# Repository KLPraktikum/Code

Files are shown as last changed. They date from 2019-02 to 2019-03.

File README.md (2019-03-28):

# Code
Sämtlicher Code (Datenbank, Klasse, Main) für das Projekt

##Kommunikationsprotokoll:
	1= gelbe Tonne
	2= schwarze Tonne
	3= grüne Tonne
	4= braune Tonne
	
	s= successful
	t= timeout

##Ablauf:
	Raspberry (1-4) -> Arduino
	Arduino steuert LEDs an
	Arduino überprüft zu benutzenden Sensor
	Arduino (s/t) -> Raspberry
	Raspberry verarbeitet Daten, je nachdem ob s oder t (Punktesystem)

##Stromverbrauch@5V
- Arduino Nano 16Mhz @ 5V - 10mA (Datenblatt)
- Propeller Board @ 5V - 300mA (Datenblatt worst case)
- VL53L0X TOF Sensor @ 3.3V - 20mA (Active)/10uA ~= 0 (Datenblatt)
- APA102 LEDs @ 5V - ~1A pro Meter bei voller Helligkeit

| Komponente 	| Leistungsaufnahme (W)  	| Duty-Cycle  	| Anzahl	|
|:-:	|:-:	|:-:	|:-:	|
| Arduino Nano  	| 0,05W  	| 100%  	|1	|
| Propeller Board  	| 1,5W  	| 100%  	|1	|
| VL53L0X  	| ((3,3×0,02×20+3,3×0,00001)÷20)×4=0,069697742W  	| 5%  	|4	|
| APA102  	| ((5W÷3)×0,05)=0,083333333W  	| 5%  	|1	|

Insgesamt: 1,6W im Durchschnitt

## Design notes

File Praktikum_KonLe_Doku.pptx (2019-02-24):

## SmartBin Public.Efficient.Easy.

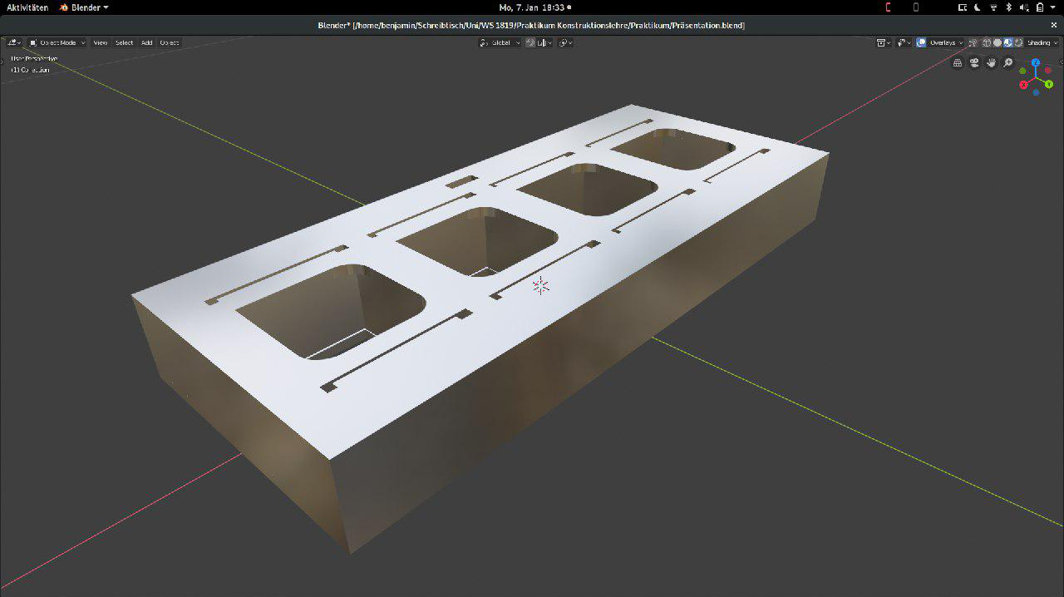
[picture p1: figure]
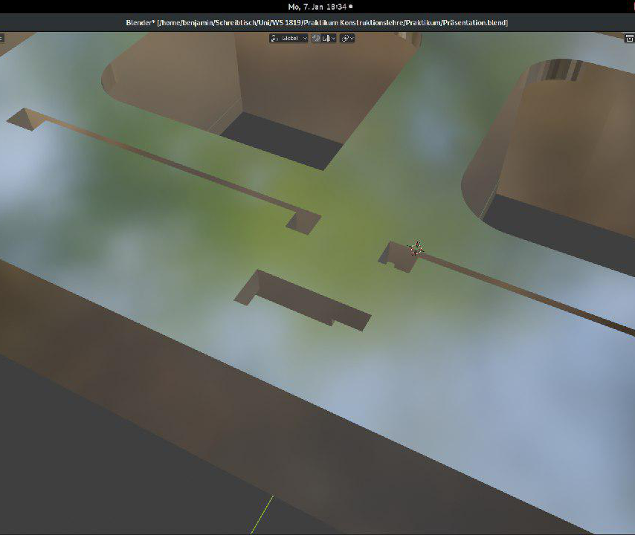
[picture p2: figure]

Präsentation für
das Praktikum Konstruktionslehre
Leitung:
Prof. Dr. Lars Mikelsons
Studenten:
Cindy Ebertz, Benjamin Ritter,
Marcel Khodabakhsh

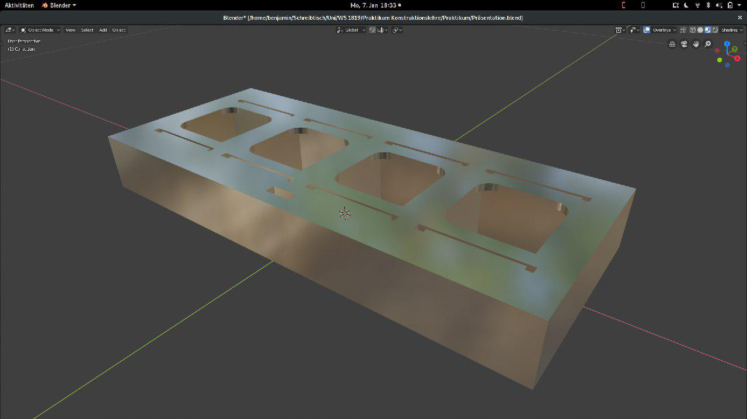
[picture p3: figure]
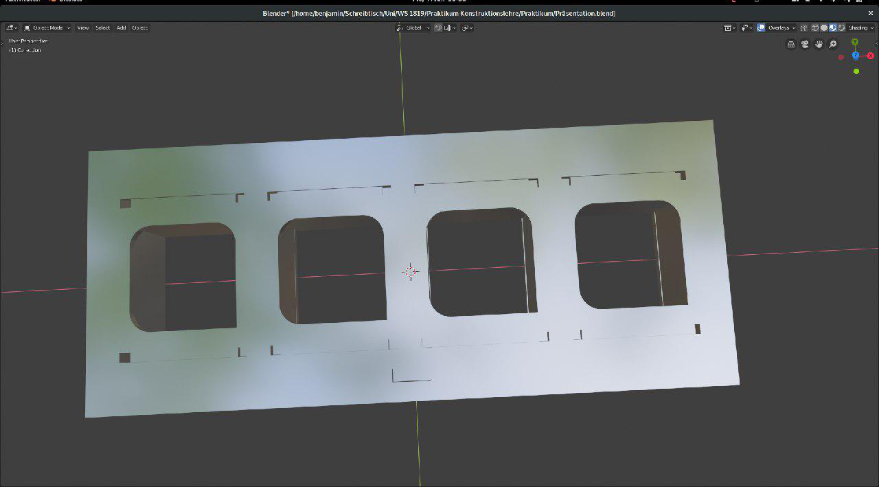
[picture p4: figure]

## Gliederung

1. Motivation für das Projekt
2. Vorführung mit Prototyp
3. Dokumentation
  a. Anforderungsermittlung
  b. Systementwurf & -architektur
  c. Systemintegration & - test
  d. Systemvalidierung

## Motivation für das Projekt

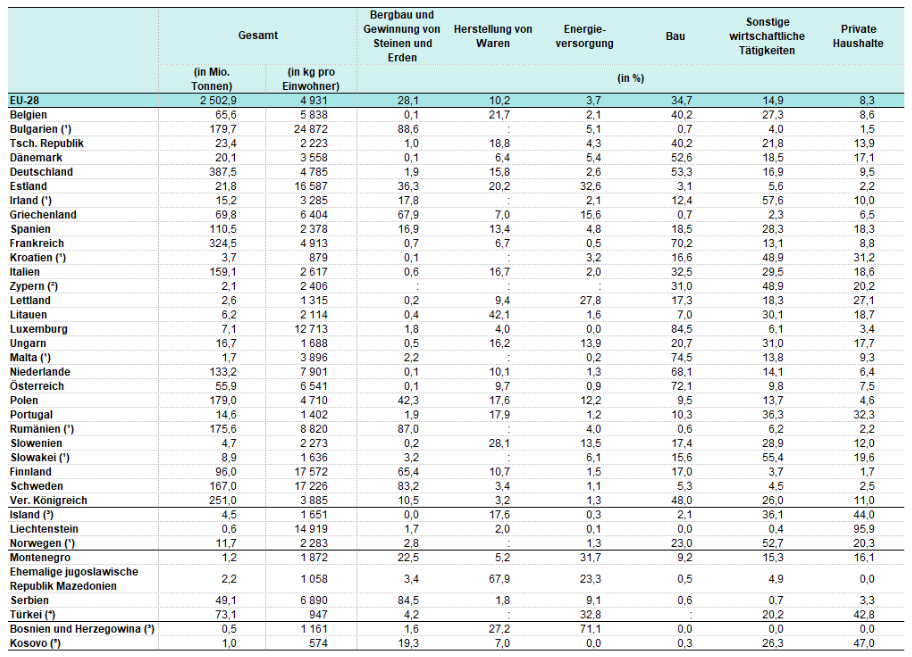
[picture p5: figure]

Praktikum Konstruktionslehre WiSe 2018/19

24.02.2019

3

- Deutschland produziert mehr Müll als jedes andere europäische Land
- Verbesserung des Recyclings für den Umweltschutz
- Unsere Mülltonne soll das vor allem an öffentlichen Plätzen / Bahnhöfen u.Ä. ermöglichen
Abbildung 1:
Abfallaufkommen in Europa
Quelle: Eurostat 2017

## Motivation für das Projekt

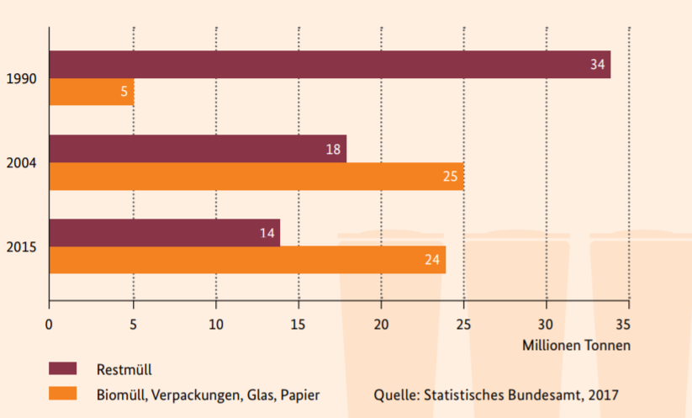
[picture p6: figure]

Praktikum Konstruktionslehre WiSe 2018/19

24.02.2019

4

- Zusätzlich ist die Menge des Biomülls, Verpackungen, Glas und Papier stark im privaten Haushalten in den letzten Jahren gestiegen
- Potenzial für Recycling
Abbildung 2:
Abfallaufkommen privater Haushalte

## Vorführung mit Prototyp

- Beispielhafte Entsorgung von einigen Produkten
→ Prototyp hat vier Entsorgungsmöglichkeiten
(Papier, Plastik, Bio, Restmüll)

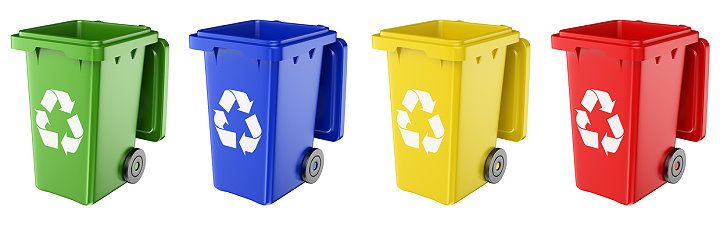
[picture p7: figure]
Bildergebnis fÃ¼r mÃ¼lltonnen

Praktikum Konstruktionslehre WiSe 2018/19

24.02.2019

5

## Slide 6

Dokumentation

Praktikum Konstruktionslehre WiSe 2018/19

24.02.2019

6

## Identifikation der Stakeholder

Stakeholder:
  - Staat / Stadtwerke (Verwendung öffentlicher Plätze)
  - Wartungsunternehmen
  - Müllabfuhr
  - Alle Nutzer der Mülltonnen
  - Partner für Bonussystem (z.B. Payback, Umweltverbände)
  - Firmen / Unternehmen entlang der Wertschöpfungskette
  - Entsorgungs- und Recyclingunternehmen

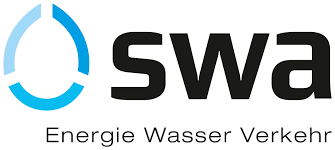
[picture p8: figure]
Bildergebnis fÃ¼r swa
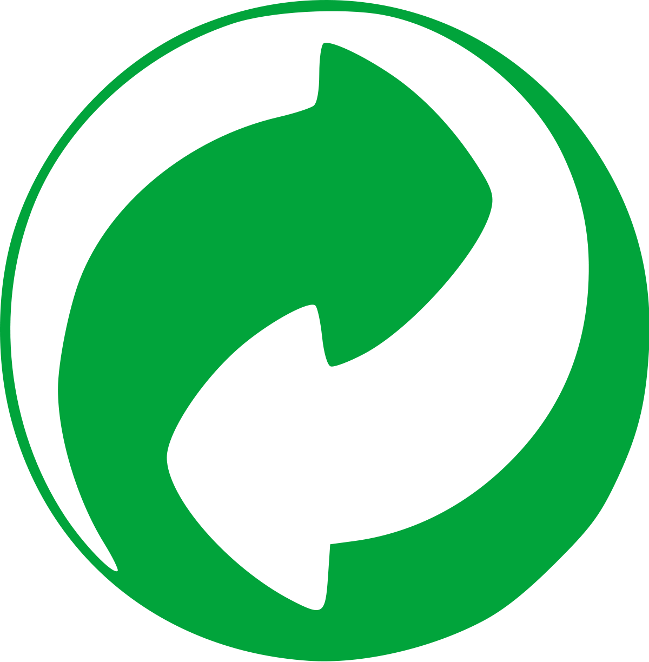
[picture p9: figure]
Bildergebnis fÃ¼r recycling zeichen
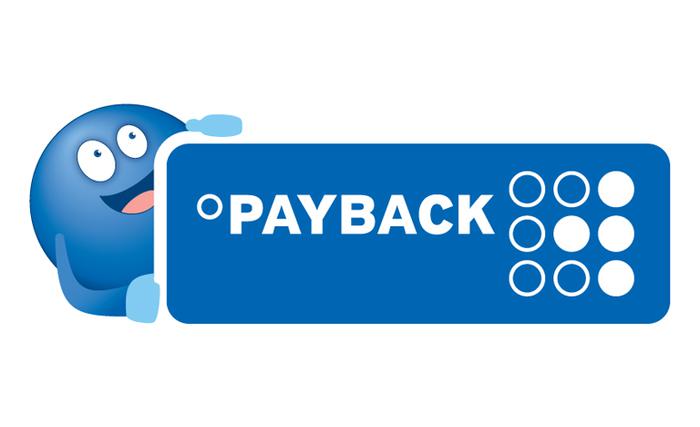
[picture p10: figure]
Bildergebnis fÃ¼r payback

Praktikum Konstruktionslehre WiSe 2018/19

24.02.2019

7

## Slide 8

Praktikum Konstruktionslehre WiSe 2018/19

24.02.2019

8

## Anforderungsermittlung und Funktionsableitung

- Systemdefinition:
  - Mülltonnenaufsatz oder ganze Mülltonne (je nach Standort)
  - Schnittstellen mit folgenden Systemen:
    - Bereits bestehende Mülltonnen (z.B. an Bahnhöfen)
    - Mit anderen smarten Mülleimern (interne Kommunikation)
    - Müllabfuhr
    - Belohnungssystem
Für die Ermittlung der Stakeholder Anforderungen haben wir uns bestmöglich in die verschiedenen Parteien hineinversetzt, da eine Kommunikation mit allen Parteien zum jetzigen Zeitpunkt zu zeitaufwändig gewesen wäre.

Praktikum Konstruktionslehre WiSe 2018/19

24.02.2019

9

## Anforderungsermittlung und Funktionsableitung

Anforderungen

Unterstützung der Nutzer

Effizienz der Tonne

Motivation für Mülltrennung schaffen

Interne Kommunikation sowie Synergie mit Umsystemen

Funktionen

Erkennen des Barcodes auf Produkten

Erkennen des Müllstands
→ Kontaktieren der Müllabfuhr

Anzeigen des richtigen Müllbehälters

Anbindung an Belohnungssysteme (z.B. PayPal)

Praktikum Konstruktionslehre WiSe 2018/19

24.02.2019

10

## House of Quality

_

_

_

| | Umfangreiche Datenbank | Mehrere Sensoren für Müllstände | Energieautark | Displaygröße & LEDs | Meldung von Sensorständen über lange Strecken
| | ↓ | ↓ | ↓ | ↓ | ↓
Einfache Benutzung | 5 | 2 | - | - | 5 | -
Kein großer Zeitaufwand | 4 | 2 | - | - | 3 | -
Vorteile durch Bonussystem | 4 | 5 | - | - | - | -
Mülltonnen nie voll | 4 | - | 5 | - | - | 5
Produkte können passend entsorgt werden | 5 | 5 | 4 | - | 3 | 4
| | 14 | 9 | - | 11 | 9

_

Technische Anforderungen

Ziele

Priorität

Kundenanforderungen

Werteskala:
1-5:
1 geringe Priorität,
5 hohe Priorität

Wichtigkeit
Σ(Priorität X Beziehung)

Praktikum Konstruktionslehre WiSe 2018/19

24.02.2019

11

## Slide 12

Praktikum Konstruktionslehre WiSe 2018/19

24.02.2019

12

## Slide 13

Umsysteme Staat (öffentliche Plätze) Müllabfuhr Nutzer Wartungsarbeiter App

Funktionen Tonne anzeigen Tonnendaten abrufen Tonne zuordnen Energie geben Elektronik schützen

Subsysteme LEDs Activity-Board Raspberry-Pi Sensoren Barcodescanner Batterien Metallhülle

Systemkontext

System

(Mülleinwurf und Tonnenfüllung)

Arduino +

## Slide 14

Logisches Modell

Müllentsorgungskonzept

Netzanschluss / Akku

LEDs

Computer 1

Computer 2

Barcode Scanner

Sensoren

Display

Computer 3

Informationsfluss

Energiefluss

Praktikum Konstruktionslehre WiSe 2018/19

24.02.2019

14

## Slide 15

Physikalisches Modell

Müllentsorgungskonzept

Powerbank

LEDs
(APA102)

Raspberry pi

Arduino

Barcode Scanner
(USB + Serialfähig)

Infrarot
Sensoren

Display

ActivityBoard

Informationsfluss

Energiefluss

Praktikum Konstruktionslehre WiSe 2018/19

24.02.2019

15

## Systementwurf- und Architektur

Variante 1 [Prototyp]: Mülltonne als Aufsatz

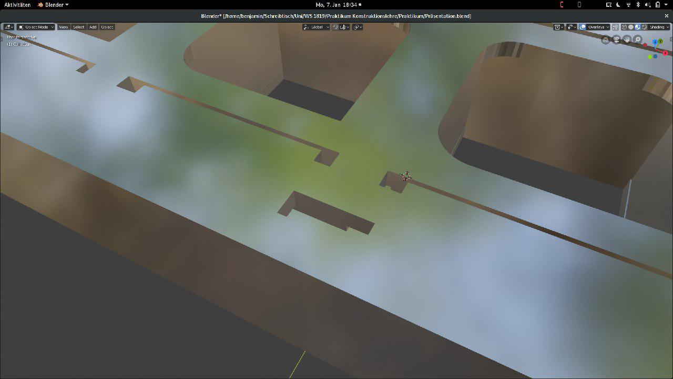
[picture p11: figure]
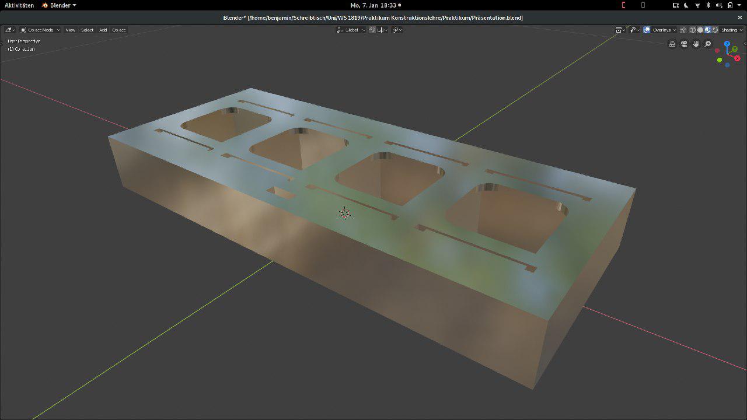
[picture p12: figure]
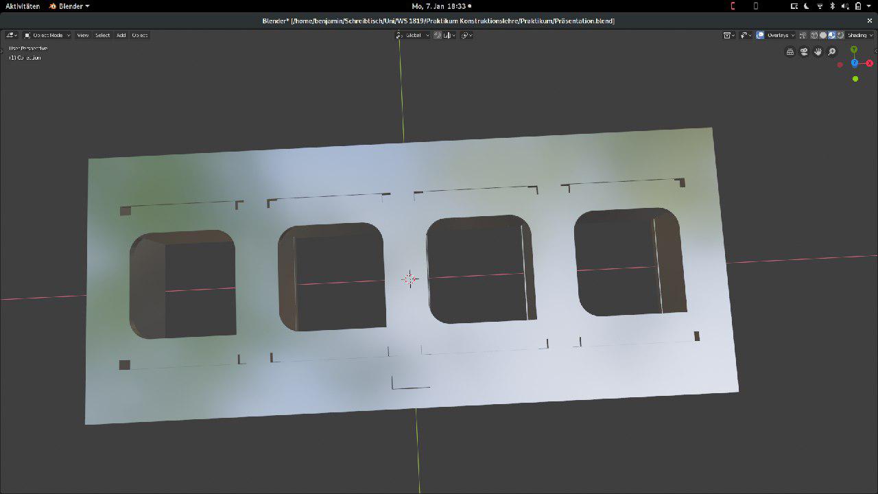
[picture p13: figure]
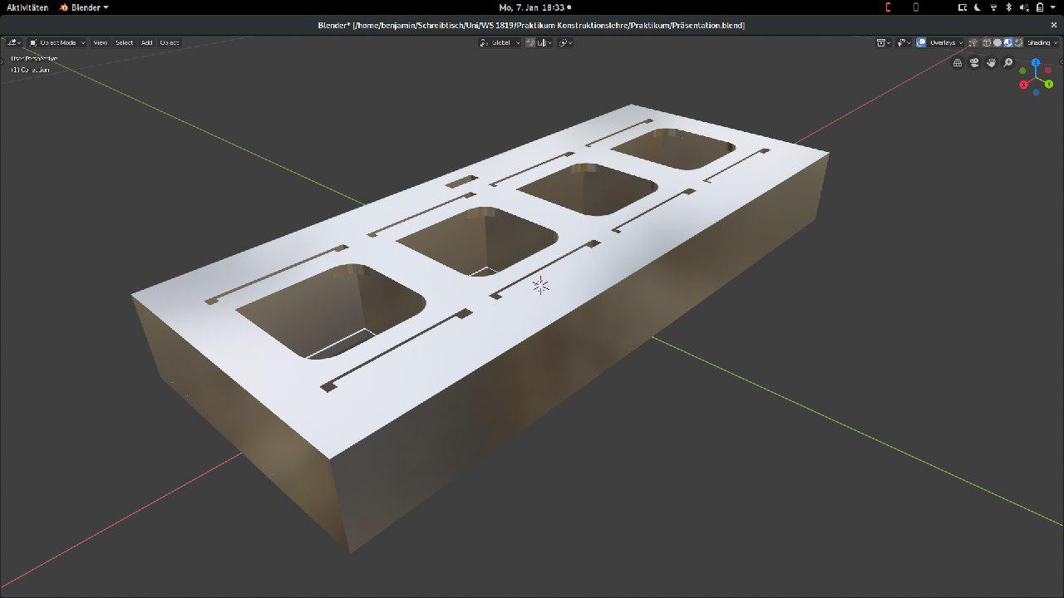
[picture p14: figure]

Praktikum Konstruktionslehre WiSe 2018/19

24.02.2019

16

## Technische Zeichnung

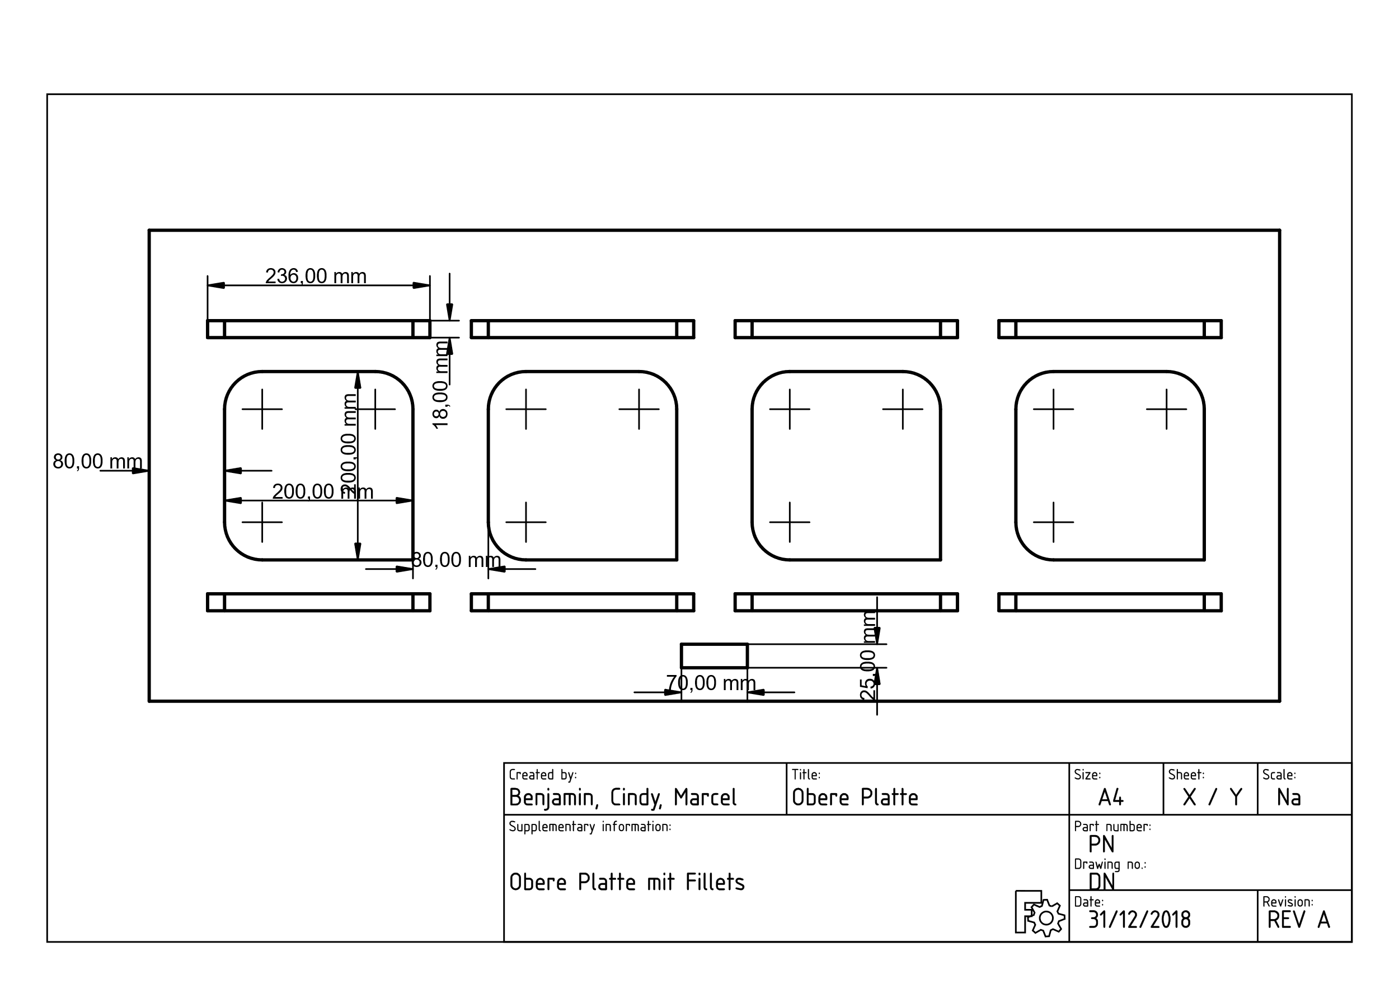
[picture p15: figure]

Praktikum Konstruktionslehre WiSe 2018/19

24.02.2019

17

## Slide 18

Praktikum Konstruktionslehre WiSe 2018/19

24.02.2019

18

## Subsystementwurf und -architektur

- Welche Domänen werden berücksichtigt?
  - Software
    - Steuerung der LEDs
    - Empfangen und Verarbeiten der Daten von Scanner und Sensoren
    - Datenbank
  - Elektronik
    - LEDs
    - Raspberry-Pi & ActivityBot
    - Barcodescanner
  - Services
    - Müllabfuhr
    - Belohnungssystem

Praktikum Konstruktionslehre WiSe 2018/19

24.02.2019

19

## Ablaufdiagramm

Standard Use Case

Abgleich mit Datenbank

Barcode scannen

Barcode in Datenbank vorhanden

Passende LED leuchtet

Bonuspunkte werden gesammelt

Barcode entspricht Kunde in Datenbank

Barcode nicht in Datenbank / nicht entsorgbar

Bonuspunkte werden gutgeschrieben

Passende Meldung für Nutzer

Praktikum Konstruktionslehre WiSe 2018/19

24.02.2019

20

Informationsfluss

Aktion

## Ablaufdiagramm

Sensorik Müllstand

Passende Meldung für Nutzer

Sensor für Müllstand

Müll fast voll

Meldung an Müllabfuhr

Müllbehälter nicht voll

Barcode scannen möglich

Müllbehälter voll

Praktikum Konstruktionslehre WiSe 2018/19

24.02.2019

21

Informationsfluss

Aktion

## Subsystementwurf und -architektur

- Weg der Daten:
  - Person -> Scanner: Barcode
  - Scanner -> Raspberry-Pi: Barcode => Suche in Datenbank

Gefunden und mind. ein Zähler > 50 | Gefunden und kein Zähler > 50 | Nicht gefunden
LEDs ansteuern (Arduino) | Warten auf Sensorendaten (RPi) | Barcode zur Datenbank hinzufügen (RPi)
Warten auf Sensorendaten (Arduino) | Jeweiligen Zähler in DB erhöhen (RPi) | Warten auf Sensorendaten (RPi)
Vergleich Tonne mit Soll und Erhöhen der Zähler (RPi) | | Erhöhen der jeweiligen Zähler in der DB (RPi)
Warten auf Barcode (RPi)
ggf. senden der Daten an Belohnungssystem (RPi)

Praktikum Konstruktionslehre WiSe 2018/19

24.02.2019

22

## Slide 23

Praktikum Konstruktionslehre WiSe 2018/19

24.02.2019

23

## Subsystemintegration und Test

- Wie werden die Systemteile integriert?
  - Prototyp
    - Metall statt Holz gibt Schutz vor Fremdeinwirkungen
    - Powerbank / Akku gibt Energie anstatt Netzanschluss / Solarpanels
  - Vorteile:
    - Leichte Wartbarkeit
    - Geringe Kosten
    - Elektronik ist geschützt vor Regen und andere Fremdeinwirkungen

Praktikum Konstruktionslehre WiSe 2018/19

24.02.2019

24

## Zigg-Zagging

Richtige Mülltonne erkenntlich machen

Smarter
Mülleimer

visuell

auditiv

LEDs

Lautsprecher

Öffnungs-mechanismus

Vorteile von LEDS:
- günstig
- Geringer Energieverbrauch
- deutliche Anzeige
- Leichte Installation und Ansteuerung

Praktikum Konstruktionslehre WiSe 2018/19

24.02.2019

25

## Zigg-Zagging

Müllstand und Mülleinwurf erkennen

Smarter
Mülleimer

auditiv

optisch

Gewichtssensor

Software/
Datenbank

Infrarot-
Sensor

haptisch

rechnerisch

Ultraschall-
Sensor

Vorteile von Infrarot Sensoren:
- günstig
- Hohe Genauigkeit
- Hohe Responserate

Praktikum Konstruktionslehre WiSe 2018/19

24.02.2019

26

## Vor- und Nachteile der Subsysteme

Subsystem | Vorteil | Nachteil | Alternative | Sonstiges
LEDs | günstig Geringer Energieverbrauch deutliche Anzeige Leichte Installation und Ansteuerung | Keine manuelle Unterstützung beim Öffnen | Motoren zum Öffnen der Mülltonnen Lautsprecher | Aus Kostengründen für LEDs entschieden.
Raspberry-Pi | Leistungsstark Günstig Python & SQL fähig USB-Host Mode Größe | Keine Library für LEDs & Sensoren | Andere PCs
Infrarot-Sensoren | günstig Hohe Genauigkeit Hohe Responserate | Bei Niederschlag und / oder hoher Lichteinstrahlung möglicherweise ungenau | Gewichtssensor Ultraschallsensor Software / Datenbank | Wir haben Infrarot-Sensoren ausleihen können.
Barcode-Scanner | Viele Produkte haben Barcodes günstig | Oft ist Zuordnung anhand von Barcodes schwierig Restmüll Zuordnung oft nicht möglich Ebenso Bio Mülltrennung schwierig | Bilderkennung | Barcode Scanner war am besten umsetzbar

Praktikum Konstruktionslehre WiSe 2018/19

24.02.2019

27

## Vor- und Nachteile der Subsysteme

Subsystem | Vorteil | Nachteil | Alternative | Sonstiges
Activity-Board | Bereits vorhanden | Schlechtere Leistung als Raspberry pi Kein Python, kein SQL SimpleIDE () | | Teil der Aufgabenstellung
Powerbank / Batterien | Ausreichend für die Stromversorgung des Prototyps portabel | Müssen ausgetauscht / geladen werden | Solarpanels / Netzanschluss
Arduino | günstig Libraries für Sensoren und LEDs vorhanden | Zusätzlicher Teil im System, welcher nicht unbedingt notwendig wäre

Praktikum Konstruktionslehre WiSe 2018/19

24.02.2019

28

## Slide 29

Praktikum Konstruktionslehre WiSe 2018/19

24.02.2019

29

## Systemintegration und Test

- Woher wissen wir, dass unser System funktioniert?
  - Testphase:
    - 6 Monate Vorlaufzeit an einer Uni
    - Nicht mit kompletter Tonne und nicht fest verschraubt (-> einfacher Transport)
    - Auffüllen der Datenbank durch Studenten (Zähler > 50)
    - Zusätzlicher Verweis auf Mülllisten bzw. Apps
    - Wöchentliche Stichproben (zur Not muss Zähler noch höher sein)
  - Späterer Verlauf:
    - Je nach Bedarf komplette Tonne oder nicht, aber in jedem Fall fest verschraubt
    - Nach Testphase noch einmal Überprüfen der Datenbank
    - Zählerstände werden verdreifacht
    - Zähler muss dreifache Menge erreichen, bis Tonne aktiv ist

Praktikum Konstruktionslehre WiSe 2018/19

24.02.2019

30

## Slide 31

Praktikum Konstruktionslehre WiSe 2018/19

24.02.2019

31

## Systemvalidierung

- Woher wissen wir, dass wir das richtige System entwickelt haben?
  - Anforderungen überprüfen
  - Social Media für User Feedback
  - Rücksprache mit allen Stakeholdern
  - Validierung durch ausgewählte Tests
    - Stromverbrauch
    - Mülleinwerfen - Erkennung

Praktikum Konstruktionslehre WiSe 2018/19

24.02.2019

32

## Systemvalidierung - Stromverbrauch

Praktikum Konstruktionslehre WiSe 2018/19

24.02.2019

33

## Systemvalidierung - Mülleinwerfen

Praktikum Konstruktionslehre WiSe 2018/19

24.02.2019

34

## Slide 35

Vielen Dank für die Aufmerksamkeit!

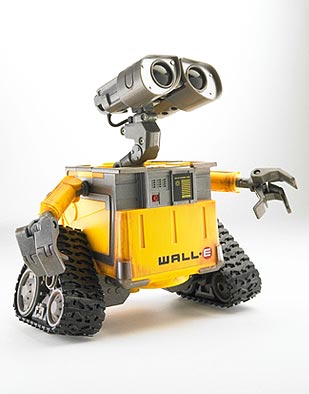
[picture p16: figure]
Bildergebnis fÃ¼r trash robot comic

Praktikum Konstruktionslehre WiSe 2018/19

24.02.2019

35

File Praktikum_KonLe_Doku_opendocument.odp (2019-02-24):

## SmartBin Public.Efficient.Easy.


Präsentation für
das Praktikum Konstruktionslehre

Leitung:

Prof. Dr. Lars Mikelsons

Studenten:

Cindy Ebertz, Benjamin Ritter,
Marcel Khodabakhsh


## Gliederung

1. Motivation für das Projekt
1. Vorführung mit Prototyp
1. Dokumentation
  a. Anforderungsermittlung
  a. Systementwurf & -architektur
  a. Systemintegration & - test
  a. Systemvalidierung

## Motivation für das Projekt


20.02.2019

Praktikum Konstruktionslehre WiSe 2018/19

3

- Deutschland produziert mehr Müll als jedes andere europäische Land
- Verbesserung des Recyclings für den Umweltschutz
- Unsere Mülltonne soll das vor allem an öffentlichen Plätzen / Bahnhöfen u.Ä. ermöglichen

Abbildung 1:
Abfallaufkommen in Europa
Quelle: Eurostat 2017

## Motivation für das Projekt

20.02.2019

Praktikum Konstruktionslehre WiSe 2018/19

4


- Zusätzlich ist die Menge des Biomülls, Verpackungen, Glas und Papier stark im privaten Haushalten in den letzten Jahren gestiegen
- Potenzial für Recycling
- Abbildung 2: Abfallaufkommen privater Haushalte

## Vorführung mit Prototyp

20.02.2019

Praktikum Konstruktionslehre WiSe 2018/19

5

- Beispielhafte Entsorgung von einigen Produkten
- Prototyp hat vier Entsorgungsmöglichkeiten (Papier, Plastik, Bio, Restmüll)

Bildergebnis fÃ¼r mÃ¼lltonnen

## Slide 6

Dokumentation

20.02.2019

Praktikum Konstruktionslehre WiSe 2018/19

6

## Identifikation der Stakeholder

20.02.2019

Praktikum Konstruktionslehre WiSe 2018/19

7

- Stakeholder:
  - Staat / Stadtwerke (Verwendung öffentlicher Plätze)
  - Wartungsunternehmen
  - Müllabfuhr
  - Alle Nutzer der Mülltonnen
  - Partner für Bonussystem (z.B. Payback, Umweltverbände)
  - Firmen / Unternehmen entlang der Wertschöpfungskette
  - Entsorgungs- und Recyclingunternehmen

Bildergebnis fÃ¼r swa
Bildergebnis fÃ¼r recycling zeichen
Bildergebnis fÃ¼r payback

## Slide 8

20.02.2019

Praktikum Konstruktionslehre WiSe 2018/19

8

## Anforderungsermittlung und Funktionsableitung

20.02.2019

Praktikum Konstruktionslehre WiSe 2018/19

9

- Systemdefinition:
  - Mülltonnenaufsatz oder ganze Mülltonne (je nach Standort)
  - Schnittstellen mit folgenden Systemen:
    - Bereits bestehende Mülltonnen (z.B. an Bahnhöfen)
    - Mit anderen smarten Mülleimern (interne Kommunikation)
    - Müllabfuhr
    - Belohnungssystem
- Für die Ermittlung der Stakeholder Anforderungen haben wir uns bestmöglich in die verschiedenen Parteien hineinversetzt, da eine Kommunikation mit allen Parteien zum jetzigen Zeitpunkt zu zeitaufwändig gewesen wäre.

## Anforderungsermittlung und Funktionsableitung

20.02.2019

Praktikum Konstruktionslehre WiSe 2018/19

10

Anforderungen

Unterstützung der Nutzer

Motivation für Mülltrennung schaffen

Interne Kommunikation sowie Synergie mit Umsystemen

Effizienz der Tonne

Funktionen

Erkennen des Barcodes auf Produkten

Erkennen des Müllstands
Kontaktieren der Müllabfuhr

Anzeigen des richtigen Müllbehälters

Anbindung an Belohnungssysteme (z.B. PayPal)

## House of Quality

Kundenanforderungen

Technische Anforderungen

20.02.2019

Praktikum Konstruktionslehre WiSe 2018/19

11

_

_

_

_

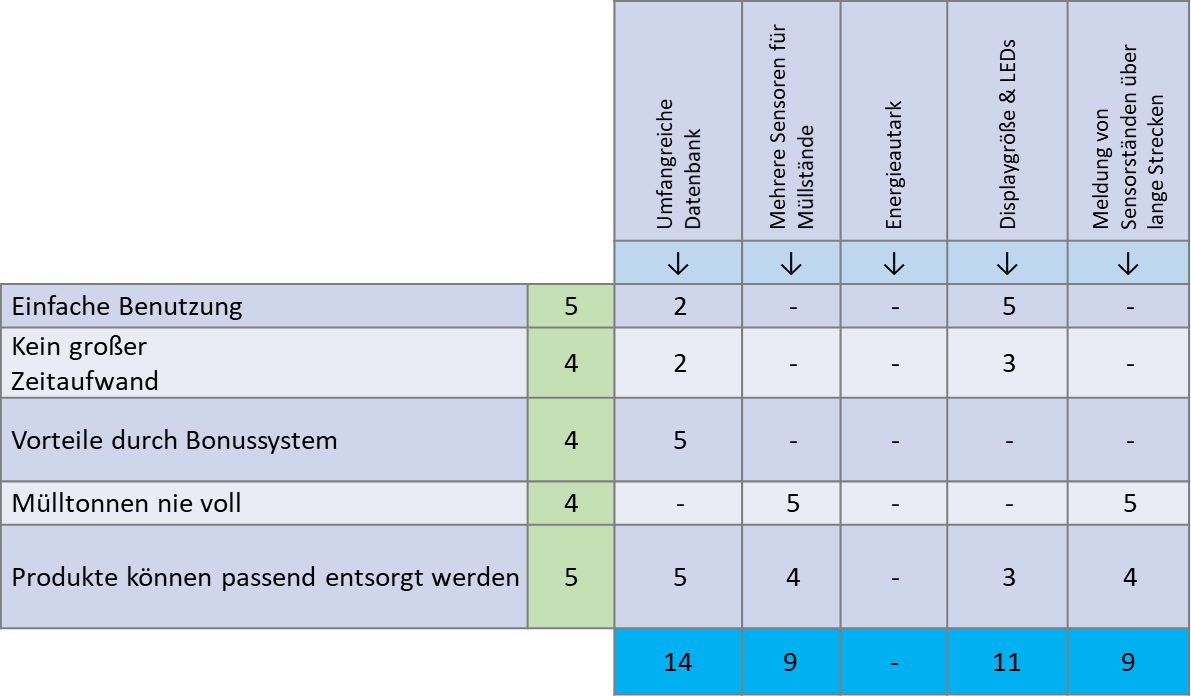
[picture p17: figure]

| | Umfangreiche Datenbank | Mehrere Sensoren für Müllstände | Energieautark | Displaygröße & LEDs | Meldung von Sensorständen über lange Strecken
| | ↓ | ↓ | ↓ | ↓ | ↓
Einfache Benutzung | 5 | 2 | - | - | 5 | -
Kein großer Zeitaufwand | 4 | 2 | - | - | 3 | -
Vorteile durch Bonussystem | 4 | 5 | - | - | - | -
Mülltonnen nie voll | 4 | - | 5 | - | - | 5
Produkte können passend entsorgt werden | 5 | 5 | 4 | - | 3 | 4
| | 14 | 9 | - | 11 | 9

Ziele

Priorität

Werteskala:
1-5:
1 geringe Priorität,
5 hohe Priorität

Wichtigkeit

Σ(Priorität X Beziehung)

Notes: 11

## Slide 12

20.02.2019

Praktikum Konstruktionslehre WiSe 2018/19

12

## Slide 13

Umsysteme Staat (öffentliche Plätze) Müllabfuhr Nutzer Wartungsarbeiter App

Funktionen Tonne anzeigen Tonnendaten abrufen Tonne zuordnen Energie geben Elektronik schützen

Subsysteme LEDs Activity-Board Raspberry-Pi Sensoren Barcodescanner Batterien Metallhülle

Systemkontext

System

(Mülleinwurf und Tonnenfüllung)

Arduino +

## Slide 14

Logisches Modell

Müllentsorgungskonzept

Informationsfluss

Energiefluss

Computer 3

Computer 2

Computer 1

Barcode Scanner

Netzanschluss / Akku

LEDs

Sensoren

Display

20.02.2019

Praktikum Konstruktionslehre WiSe 2018/19

14

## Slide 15

Informationsfluss

Energiefluss

ActivityBoard

Arduino

Raspberry pi

Barcode Scanner
(USB + Serialfähig)

Powerbank

LEDs
(APA102)

Infrarot
Sensoren

Display

20.02.2019

Praktikum Konstruktionslehre WiSe 2018/19

15

Physikalisches Modell

Müllentsorgungskonzept

## Systementwurf- und Architektur

20.02.2019

Praktikum Konstruktionslehre WiSe 2018/19

17

- Variante 1 [Prototyp]: Mülltonne als Aufsatz


## Technische Zeichnung

20.02.2019

Praktikum Konstruktionslehre WiSe 2018/19

18

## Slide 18

20.02.2019

Praktikum Konstruktionslehre WiSe 2018/19

19

## Subsystementwurf und -architektur

20.02.2019

Praktikum Konstruktionslehre WiSe 2018/19

20

- Welche Domänen werden berücksichtigt?
  - Software
    - Steuerung der LEDs
    - Empfangen und Verarbeiten der Daten von Scanner und Sensoren
    - Datenbank
  - Elektronik
    - LEDs
    - Raspberry-Pi & ActivityBot
    - Barcodescanner
  - Services
    - Müllabfuhr
    - Belohnungssystem

## Ablaufdiagramm

Informationsfluss

Aktion

Barcode scannen

Abgleich mit Datenbank

Barcode in Datenbank vorhanden

Barcode entspricht Kunde in Datenbank

Bonuspunkte werden gutgeschrieben

Barcode nicht in Datenbank / nicht entsorgbar

Passende Meldung für Nutzer

Passende LED leuchtet

Bonuspunkte werden gesammelt

20.02.2019

Praktikum Konstruktionslehre WiSe 2018/19

21

Standard Use Case

## Ablaufdiagramm

Informationsfluss

Aktion

Müllbehälter voll

Sensor für Müllstand

Müllbehälter nicht voll

Barcode scannen möglich

Passende Meldung für Nutzer

Müll fast voll

Meldung an Müllabfuhr

20.02.2019

Praktikum Konstruktionslehre WiSe 2018/19

22

Sensorik Müllstand

## Subsystementwurf und -architektur

20.02.2019

Praktikum Konstruktionslehre WiSe 2018/19

23

- Weg der Daten:
  - Person -> Scanner: Barcode
  - Scanner -> Raspberry-Pi: Barcode => Suche in Datenbank

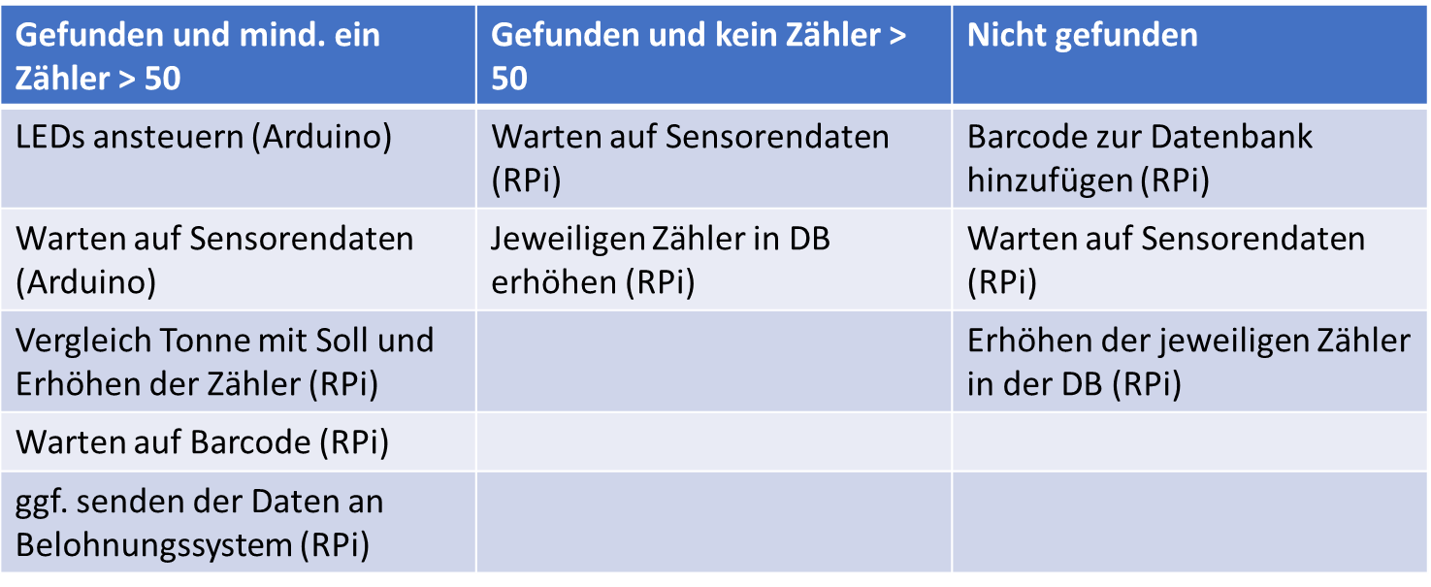
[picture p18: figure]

Gefunden und mind. ein Zähler > 50 | Gefunden und kein Zähler > 50 | Nicht gefunden
LEDs ansteuern (Arduino) | Warten auf Sensorendaten (RPi) | Barcode zur Datenbank hinzufügen (RPi)
Warten auf Sensorendaten (Arduino) | Jeweiligen Zähler in DB erhöhen (RPi) | Warten auf Sensorendaten (RPi)
Vergleich Tonne mit Soll und Erhöhen der Zähler (RPi) | | Erhöhen der jeweiligen Zähler in der DB (RPi)
Warten auf Barcode (RPi)
ggf. senden der Daten an Belohnungssystem (RPi)

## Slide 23

20.02.2019

Praktikum Konstruktionslehre WiSe 2018/19

24

## Subsystemintegration und Test

20.02.2019

Praktikum Konstruktionslehre WiSe 2018/19

25

- Wie werden die Systemteile integriert?
  - Prototyp
    - Metall statt Holz gibt Schutz vor Fremdeinwirkungen
    - Powerbank / Akku gibt Energie anstatt Netzanschluss / Solarpanels
  - Vorteile:
    - Leichte Wartbarkeit
    - Geringe Kosten
    - Elektronik ist geschützt vor Regen und andere Fremdeinwirkungen

## Zigg-Zagging

20.02.2019

Praktikum Konstruktionslehre WiSe 2018/19

26

Richtige Mülltonne erkenntlich machen

Smarter
Mülleimer

visuell

auditiv

Öffnungs-mechanismus

Lautsprecher

LEDs

Vorteile von LEDS:

- günstig
- Geringer Energieverbrauch
- deutliche Anzeige
- Leichte Installation und Ansteuerung

## Zigg-Zagging

20.02.2019

Praktikum Konstruktionslehre WiSe 2018/19

27

Müllstand und Mülleinwurf erkennen

Smarter
Mülleimer

auditiv

optisch

Infrarot-
Sensor

Software/
Datenbank

Gewichtssensor

haptisch

rechnerisch

Ultraschall-
Sensor

Vorteile von Infrarot Sensoren:

- günstig
- Hohe Genauigkeit
- Hohe Responserate

## Vor- und Nachteile der Subsysteme

20.02.2019

Praktikum Konstruktionslehre WiSe 2018/19

28

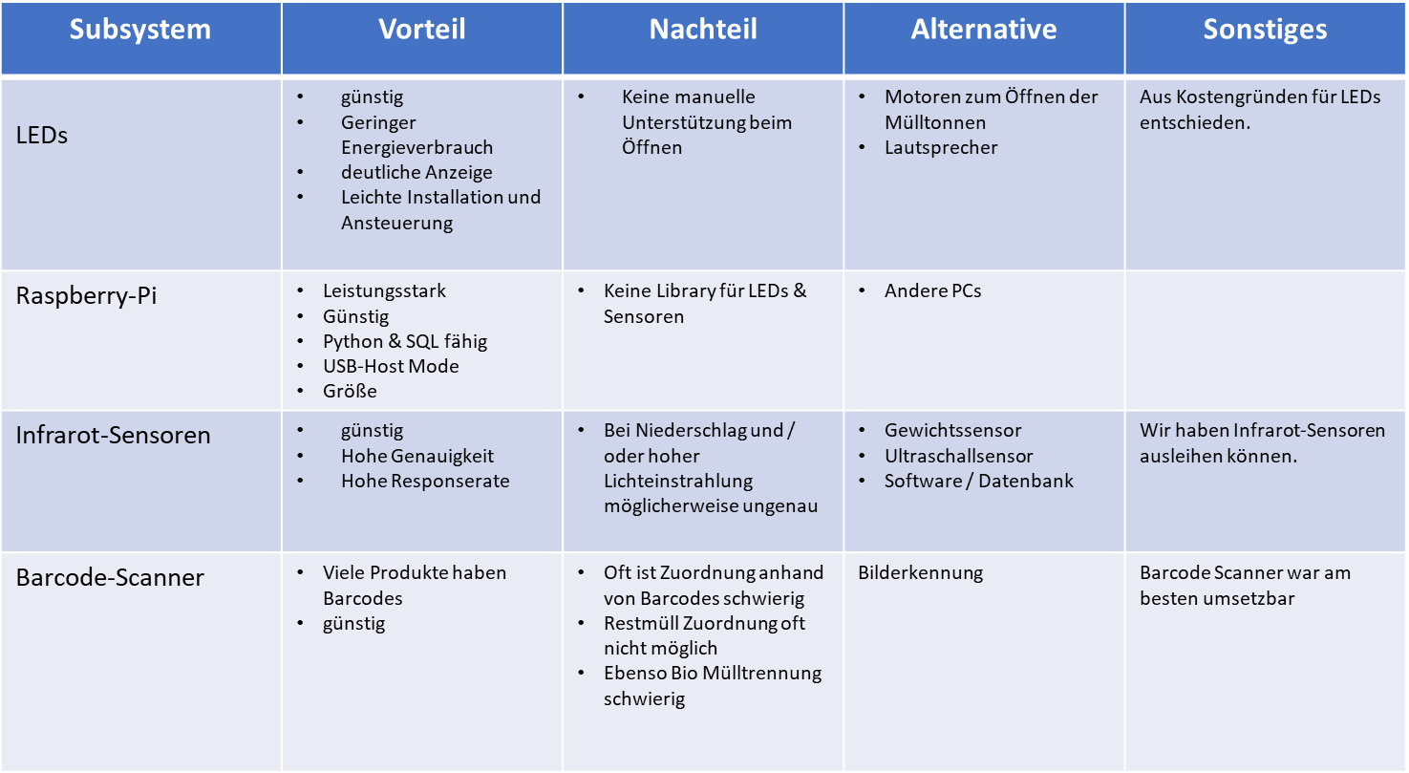
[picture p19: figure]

Subsystem | Vorteil | Nachteil | Alternative | Sonstiges
LEDs | günstig Geringer Energieverbrauch deutliche Anzeige Leichte Installation und Ansteuerung | Keine manuelle Unterstützung beim Öffnen | Motoren zum Öffnen der Mülltonnen Lautsprecher | Aus Kostengründen für LEDs entschieden.
Raspberry-Pi | Leistungsstark Günstig Python & SQL fähig USB-Host Mode Größe | Keine Library für LEDs & Sensoren | Andere PCs
Infrarot-Sensoren | günstig Hohe Genauigkeit Hohe Responserate | Bei Niederschlag und / oder hoher Lichteinstrahlung möglicherweise ungenau | Gewichtssensor Ultraschallsensor Software / Datenbank | Wir haben Infrarot-Sensoren ausleihen können.
Barcode-Scanner | Viele Produkte haben Barcodes günstig | Oft ist Zuordnung anhand von Barcodes schwierig Restmüll Zuordnung oft nicht möglich Ebenso Bio Mülltrennung schwierig | Bilderkennung | Barcode Scanner war am besten umsetzbar

## Vor- und Nachteile der Subsysteme

20.02.2019

Praktikum Konstruktionslehre WiSe 2018/19

29

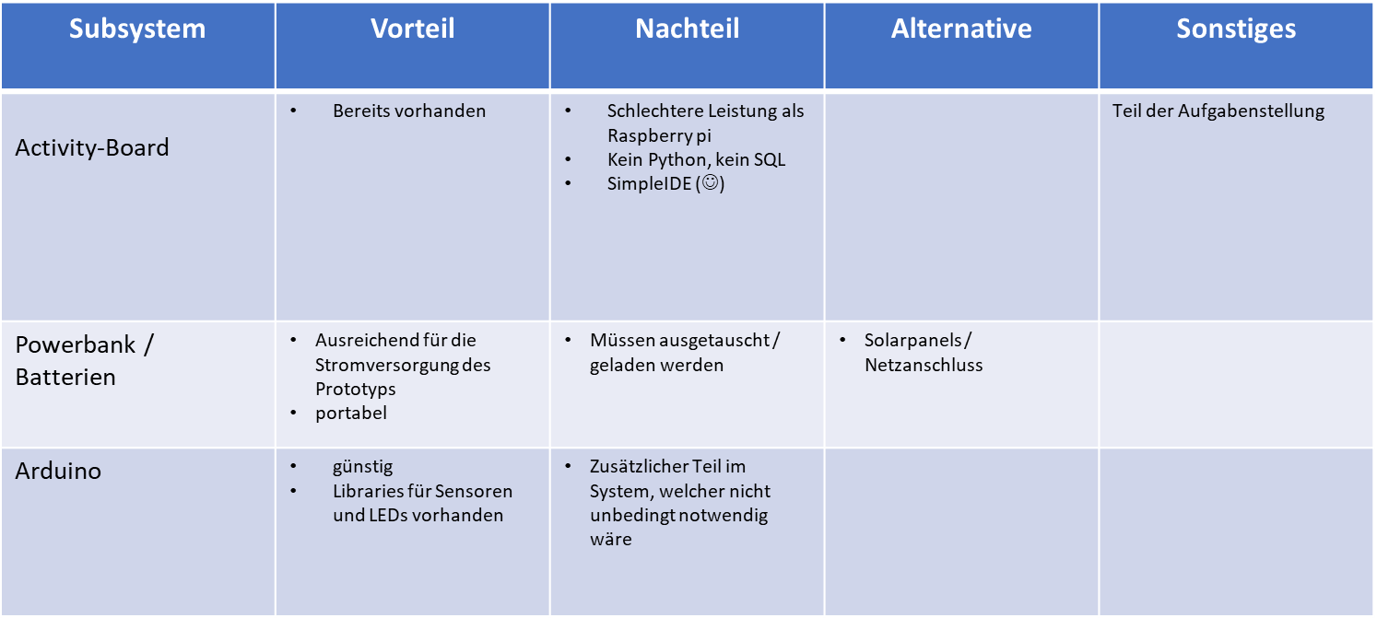
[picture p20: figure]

Subsystem | Vorteil | Nachteil | Alternative | Sonstiges
Activity-Board | Bereits vorhanden | Schlechtere Leistung als Raspberry pi Kein Python, kein SQL SimpleIDE () | | Teil der Aufgabenstellung
Powerbank / Batterien | Ausreichend für die Stromversorgung des Prototyps portabel | Müssen ausgetauscht / geladen werden | Solarpanels / Netzanschluss
Arduino | günstig Libraries für Sensoren und LEDs vorhanden | Zusätzlicher Teil im System, welcher nicht unbedingt notwendig wäre

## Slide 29

20.02.2019

Praktikum Konstruktionslehre WiSe 2018/19

30

## Systemintegration und Test

20.02.2019

Praktikum Konstruktionslehre WiSe 2018/19

31

- Woher wissen wir, dass unser System funktioniert?
  - Testphase:
    - 6 Monate Vorlaufzeit an einer Uni
    - Nicht mit kompletter Tonne und nicht fest verschraubt (-> einfacher Transport)
    - Auffüllen der Datenbank durch Studenten (Zähler > 50)
    - Zusätzlicher Verweis auf Mülllisten bzw. Apps
    - Wöchentliche Stichproben (zur Not muss Zähler noch höher sein)
  - Späterer Verlauf:
    - Je nach Bedarf komplette Tonne oder nicht, aber in jedem Fall fest verschraubt
    - Nach Testphase noch einmal Überprüfen der Datenbank
    - Zählerstände werden verdreifacht
    - Zähler muss dreifache Menge erreichen, bis Tonne aktiv ist

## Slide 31

20.02.2019

Praktikum Konstruktionslehre WiSe 2018/19

32

## Systemvalidierung

20.02.2019

Praktikum Konstruktionslehre WiSe 2018/19

33

- Woher wissen wir, dass wir das richtige System entwickelt haben?
  - Anforderungen überprüfen
  - Social Media für User Feedback
  - Rücksprache mit allen Stakeholdern
  - Validierung durch ausgewählte Tests
    - Stromverbrauch
    - Mülleinwerfen - Erkennung

## Systemvalidierung - Stromverbrauch

20.02.2019

Praktikum Konstruktionslehre WiSe 2018/19

34

## Systemvalidierung - Mülleinwerfen

20.02.2019

Praktikum Konstruktionslehre WiSe 2018/19

35

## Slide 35

20.02.2019

Praktikum Konstruktionslehre WiSe 2018/19

36

- Vielen Dank für die Aufmerksamkeit!

Bildergebnis fÃ¼r trash robot comic

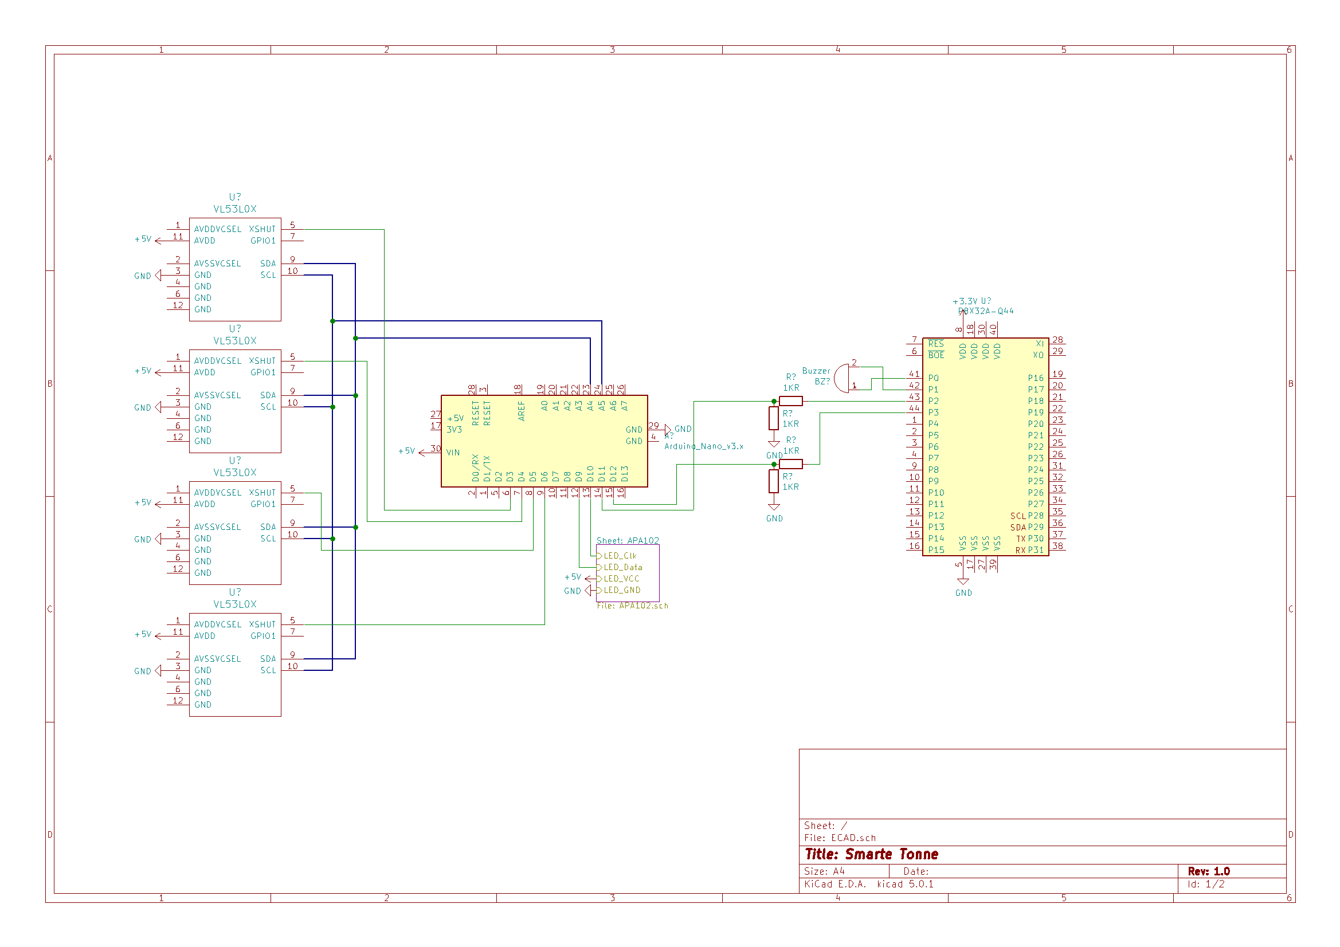
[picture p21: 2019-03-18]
CAD/ECAD/Schematic.png

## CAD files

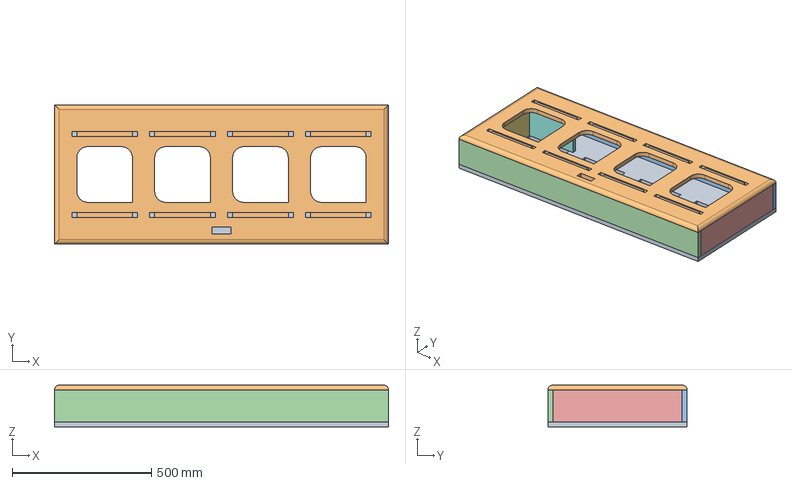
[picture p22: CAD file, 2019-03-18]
CAD/TonneV2.FCstd
1200.0 x 500.0 x 150.0 mm
Boden
Deckel
Backplate
Faceplate
Rechts
Links
LochAbdeckungLinks
LochAbdeckungOben

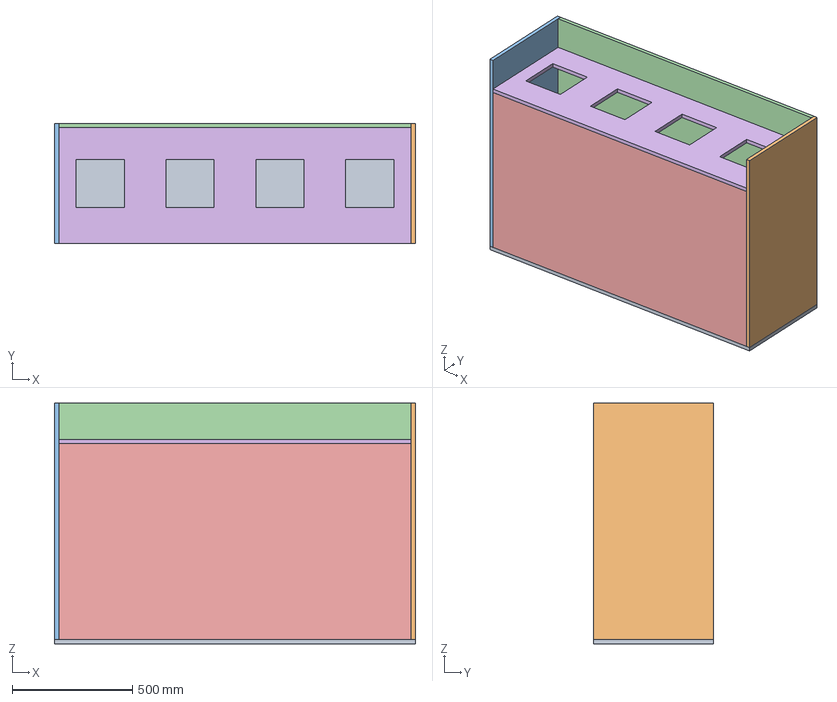
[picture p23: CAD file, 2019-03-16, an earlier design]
CAD/Tonne.FCstd
1500.0 x 500.0 x 1000.0 mm
Boden
WandRechts
WandLinks
Rückplatte
Vorderplatte
Zwischenplatte

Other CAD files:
CAD/Präsentation.blend

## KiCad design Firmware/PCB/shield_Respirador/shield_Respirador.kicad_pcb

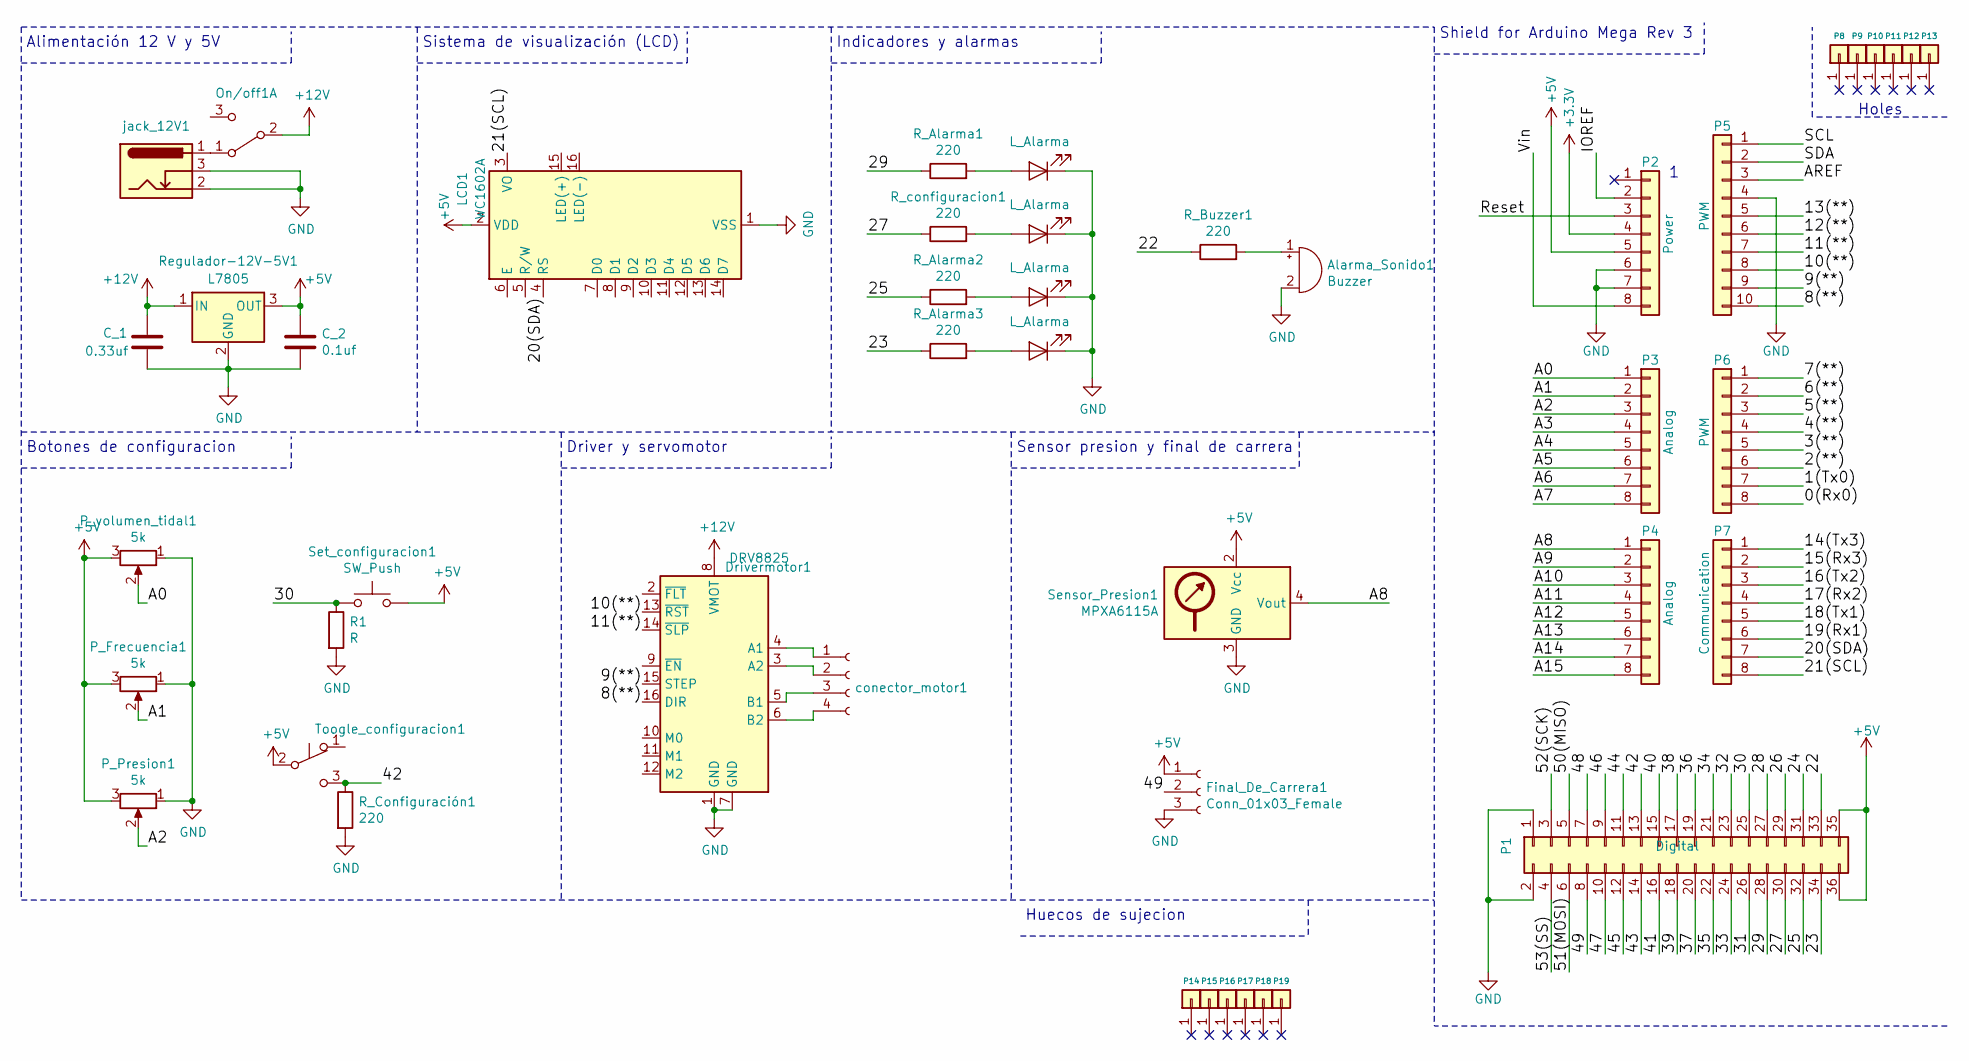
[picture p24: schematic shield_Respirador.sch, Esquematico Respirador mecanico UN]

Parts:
Alarma_Sonido1: Buzzer; MagneticBuzzer_ProSignal_ABI-009-RC
C_1: 0.33uf; C_Disc_D3.0mm_W1.6mm_P2.50mm
C_2: 0.1uf; C_Disc_D3.0mm_W1.6mm_P2.50mm
D1, D2, D3, D4: L_Alarma; LED_D5.0mm
Drivermotor1: DRV8825; Pololu_Breakout-16_15.2x20.3mm
Final_De_Carrera1: Conn_01x03_Female; PinSocket_1x03_P2.00mm_Vertical
LCD1: WC1602A
On/off1: SW_DPDT_x2; TerminalBlock_bornier-3_P5.08mm
P1: Digital; Socket_Strip_Arduino_2x18
P2: Power; Socket_Strip_Arduino_1x08
P3, P4: Analog; Socket_Strip_Arduino_1x08
P5: PWM; Socket_Strip_Arduino_1x10
P6: PWM; Socket_Strip_Arduino_1x08
P7: Communication; Socket_Strip_Arduino_1x08
P8, P9, P10, P11, P12, P13, P14, P15, P16, P17, P18, P19: CONN_01X01; Arduino_1pin
P_Frecuencia1: 5k; Potentiometer_Alpha_RD901F-40-00D_Single_Vertical
P_Presion1: 5k; Potentiometer_Alpha_RD901F-40-00D_Single_Vertical
P_volumen_tidal1: 5k; Potentiometer_Alpha_RD901F-40-00D_Single_Vertical
R1: R; R_Axial_DIN0207_L6.3mm_D2.5mm_P10.16mm_Horizontal
R_Alarma1, R_Alarma2, R_Alarma3: 220; R_Axial_DIN0207_L6.3mm_D2.5mm_P10.16mm_Horizontal
R_Buzzer1: 220; R_Axial_DIN0207_L6.3mm_D2.5mm_P10.16mm_Horizontal
R_Configuración1: 220; R_Axial_DIN0207_L6.3mm_D2.5mm_P10.16mm_Horizontal
R_configuracion1: 220; R_Axial_DIN0207_L6.3mm_D2.5mm_P10.16mm_Horizontal
Regulador-12V-5V1: L7805; TO-220-3_Vertical
Sensor_Presion1: MPXA6115A; DIP-8_W7.62mm_LongPads
Set_configuracion1: SW_Push; TerminalBlock_bornier-2_P5.08mm
Toogle_configuracion1: SW_Push_SPDT; TerminalBlock_bornier-3_P5.08mm
conector_motor1: Conn_01x04_Female; PinSocket_1x04_P2.00mm_Vertical
jack_12V1: Alimentacion_12V; BarrelJack_Horizontal

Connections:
+3V3: P2.4
+5V: C_2.1, Final_De_Carrera1.1, LCD1.2 (VDD), P1.35, P1.36, P2.5, P_Frecuencia1.3, P_Presion1.3, P_volumen_tidal1.3, Regulador-12V-5V1.3 (OUT), Sensor_Presion1.2 (Vcc), Set_configuracion1.2, Toogle_configuracion1.2 (B)
+12V: C_1.1, Drivermotor1.8 (VMOT), On/off1.2 (B), Regulador-12V-5V1.1 (IN)
/0(Rx0): P6.8
/1(Tx0): P6.7
/2(**): P6.6
/3(**): P6.5
/4(**): P6.4
/5(**): P6.3
/6(**): P6.2
/7(**): P6.1
/8(**): Drivermotor1.16 (DIR), P5.10
/9(**): Drivermotor1.15 (STEP), P5.9
/10(**): Drivermotor1.13 (~RST), P5.8
/11(**): Drivermotor1.14 (~SLP), P5.7
/12(**): P5.6
/13(**): P5.5
/14(Tx3): P7.1
/15(Rx3): P7.2
/16(Tx2): P7.3
/17(Rx2): P7.4
/18(Tx1): P7.5
/19(Rx1): P7.6
/20(SDA): LCD1.4 (RS), P7.7
/21(SCL): LCD1.3 (VO), P7.8
/22: P1.33, R_Buzzer1.1
/23: P1.34, R_Alarma3.1
/24: P1.31
/25: P1.32, R_Alarma2.1
/26: P1.29
/27: P1.30, R_configuracion1.1
/28: P1.27
/29: P1.28, R_Alarma1.1
/30: P1.25, R1.1, Set_configuracion1.1
/31: P1.26
/32: P1.23
/33: P1.24
/34: P1.21
/35: P1.22
/36: P1.19
/37: P1.20
/38: P1.17
/39: P1.18
/40: P1.15
/41: P1.16
/42: P1.13, R_Configuración1.1, Toogle_configuracion1.3 (C)
/43: P1.14
/44: P1.11
/45: P1.12
/46: P1.9
/47: P1.10
/48: P1.7
/49: Final_De_Carrera1.2, P1.8
/50(MISO): P1.5
/51(MOSI): P1.6
/52(SCK): P1.3
/53(SS): P1.4
/A0: P3.1, P_volumen_tidal1.2
/A1: P3.2, P_Frecuencia1.2
/A2: P3.3, P_Presion1.2
/A3: P3.4
/A4: P3.5
/A5: P3.6
/A6: P3.7
/A7: P3.8
/A8: P4.1, Sensor_Presion1.4 (Vout)
/A9: P4.2
/A10: P4.3
/A11: P4.4
/A12: P4.5
/A13: P4.6
/A14: P4.7
/A15: P4.8
/AREF: P5.3
/IOREF: P2.2
/Reset: P2.3
/SCL: P5.1
/SDA: P5.2
/Vin: P2.8
GND: Alarma_Sonido1.2 (+), C_1.2, C_2.2, D1.1 (K), D2.1 (K), D3.1 (K), D4.1 (K), Drivermotor1.1 (GND), Drivermotor1.7 (GND), Final_De_Carrera1.3, LCD1.1 (VSS), P1.1, P1.2, P2.6, P2.7, P5.4, P_Frecuencia1.1, P_Presion1.1, P_volumen_tidal1.1, R1.2, R_Configuración1.2, Regulador-12V-5V1.2 (GND), Sensor_Presion1.3 (GND), jack_12V1.2, jack_12V1.3
unnamed: Alarma_Sonido1.1 (-), R_Buzzer1.2
unnamed: D1.2 (A), R_Alarma1.2
unnamed: D2.2 (A), R_configuracion1.2
unnamed: D3.2 (A), R_Alarma2.2
unnamed: D4.2 (A), R_Alarma3.2
unnamed: Drivermotor1.3 (A2), conector_motor1.2
unnamed: Drivermotor1.4 (A1), conector_motor1.1
unnamed: Drivermotor1.5 (B1), conector_motor1.3
unnamed: Drivermotor1.6 (B2), conector_motor1.4
unnamed: On/off1.1 (A), jack_12V1.1

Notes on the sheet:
Shield for Arduino Mega Rev 3
Holes
Indicadores y alarmas
Sistema de visualización (LCD)
Alimentación 12 V y 5V
Botones de configuracion
Driver y servomotor
Sensor presion y final de carrera
Huecos de sujecion

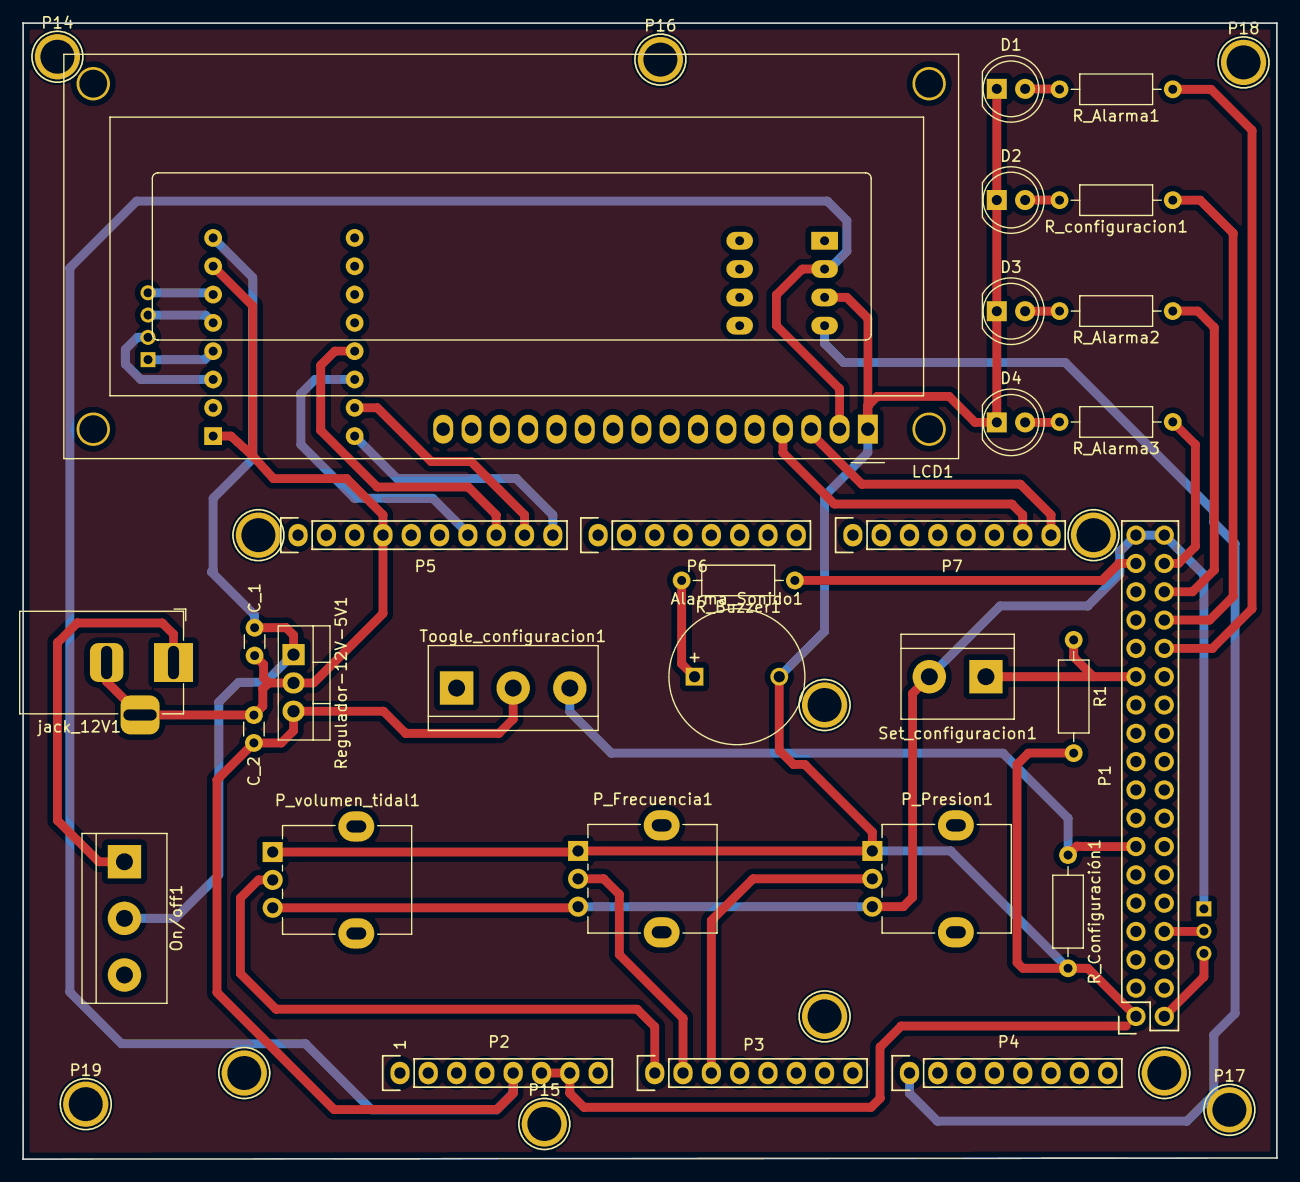
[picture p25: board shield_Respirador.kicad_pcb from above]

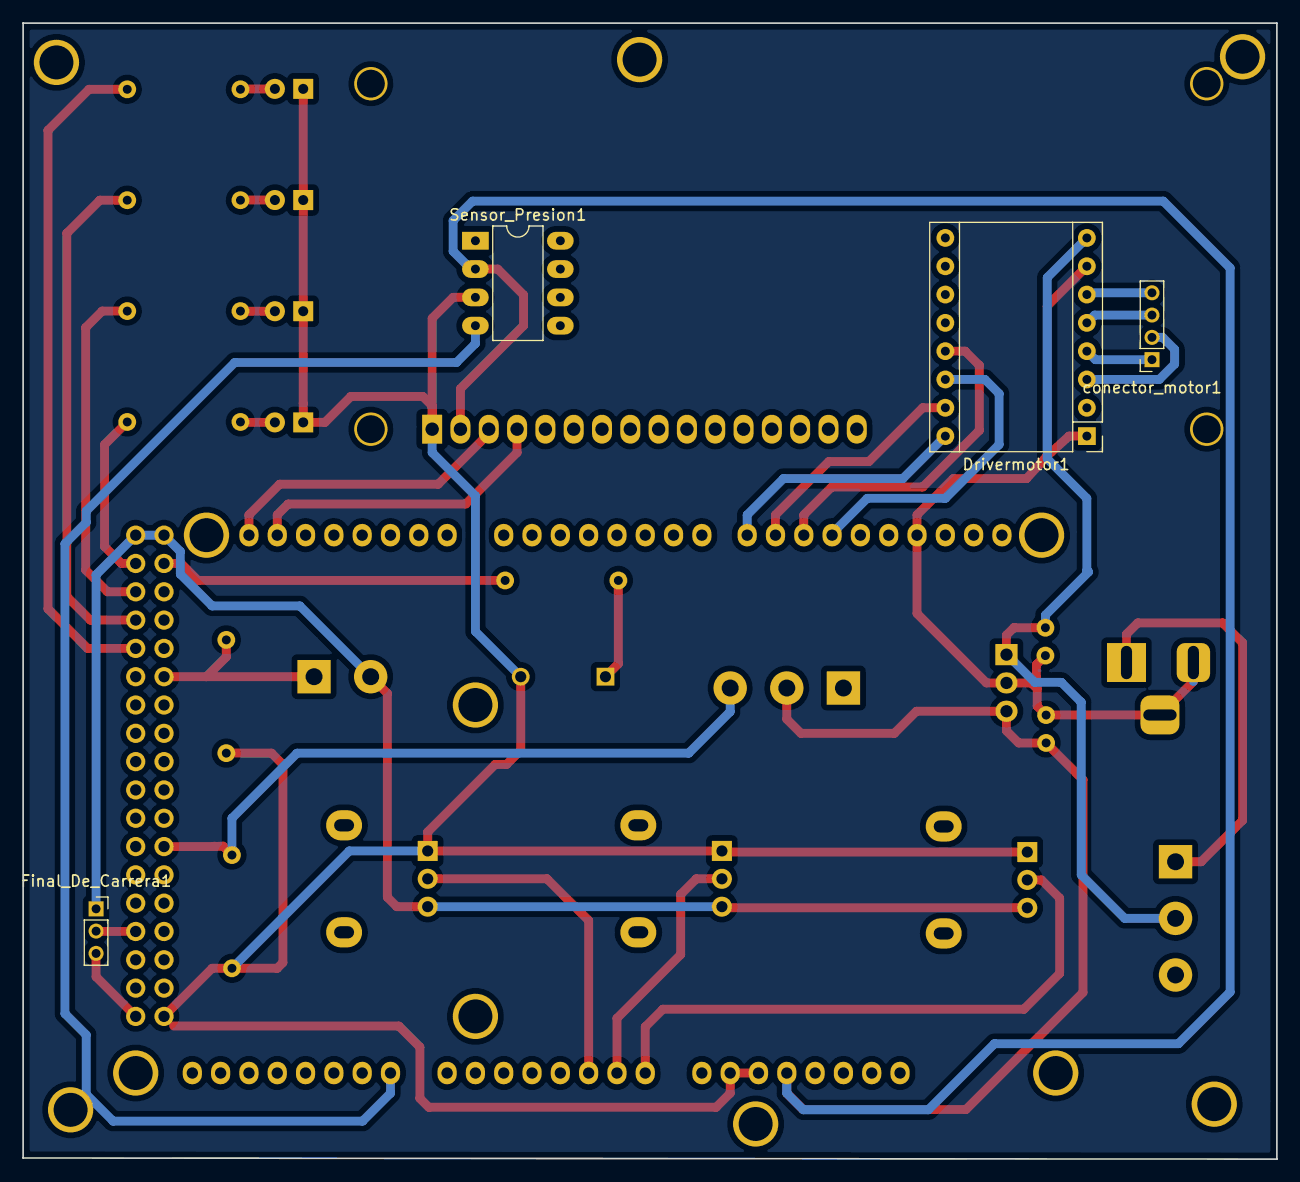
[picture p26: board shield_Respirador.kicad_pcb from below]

Board: 2 copper layers, 112.5 x 101.9 mm, 46 parts (4 on the bottom side), 31 nets.

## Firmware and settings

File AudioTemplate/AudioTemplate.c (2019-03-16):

#include "abdrive.h"
#include "simpletools.h"
#include "wifi.h"
#include "servo.h"
#include "ping.h"


int i = 0;
char string_hilfe1 [9];
char string_hilfe2[9];
char stringvorne[200];
char stringmittevorne[200];
char stringmittehinten[200];
char stringhinten[200];
int event, id, handle;
int getFromPageId1, getFromPageId2;
int postFromPageId;
int getFromPageId3;
volatile int *thread = 0;
volatile int run = 0;
volatile int labyL = 0;
volatile int labyTerminate = 0;

void labyrinth();
void laby_timer();
void musicplay();
void musicplay3();
void musicplaygot();

/* intlen ist eine  Hilfsfunktion, welche die Laenge des Strings ueberprueft */

int intlen(int i){
    if(i < 10)
        return 1;
    else if(i < 100)
        return 2;
    else if(i > 99)
        return 3;
}

/* setPingoServo setzt den Servo auf den gewuenschten Winkel */

void setPingServo(int degree, int pin) {
  servo_angle(pin, degree);
  int pause_time = 150;
  if(degree == 0) {
    pause_time = 150;
  }else{
    pause_time = 150;
  }
  pause(pause_time);
}

/* teilen ist eine Hilfsfunktion zum Teilen der Strings, um PingData an JavaScript uebermitteln zu koennen.*/

int teilen(int help, char *stringto){
  int hundert = help/100;
  int zehn = (help - hundert*100) / 10;
  int eins = help-hundert*100-zehn*10;
  
  int k = 0;
  if(hundert!=0){
    stringto[k++] = hundert + '0';
  }   
  if(zehn!=0){
    stringto[k++] = zehn + '0';
  }   
  stringto[k++] = eins + '0';
  stringto[k++] = '_';
  return k;  
  
}

/*ping_around misst mit 2 PINGS und 2 Servo Motoren alle 3 Grad um den Roboter.*/

void ping_around(){
  stringvorne[0] = '\0';
  stringmittevorne[0] = '\0'; 
  stringmittehinten[0] = '\0'; 
  stringhinten[0] = '\0';
   int l1 = 0;
   int l2 = 0;
   int l3 = 0;
   int l4 = 0;
   int help = 0;
  for(i = 0; i <= 180; i = i+6){
    
       setPingServo(i*10, 16);
      setPingServo(i*10, 17);
     if( i <= 90){
       help = ping_cm(11);
       l1 += teilen(help, stringvorne + (l1*sizeof(char)));
       //sprintf(stringvorne,"%i_",help);
       //l1 += intlen(help) + 1;
               

       help = ping_cm(10);
       //stringmittehinten[x] = help;
       //sprintf(stringmittehinten,"%i_",help);
       l2 += teilen(help, stringmittehinten + (l2*sizeof(char)));
       //stringmittehinten[x++] = '_'; 
     }else if(i > 90){
       help = ping_cm(11);
      // sprintf(stringmittevorne,"%i_",help);
       l3 += teilen(help, stringmittevorne + (l3*sizeof(char)));
               

       help = ping_cm(10);
       l4 += teilen(help, stringhinten + (l4*sizeof(char)));
       
     }              
     
  }
 stringvorne[l1 -1] = '\0';
 stringmittevorne[l3 - 1] = '\0';
 stringmittehinten[l2 - 1] = '\0';
 stringhinten[l4 - 1] = '\0';
 servo_angle(16, 0);
 servo_angle(17, 0);
}

int main(){
	
  drive_setAcceleration(0,200);
  drive_setAcceleration(1,400);
  drive_speed(0,0);
  /*run = 1;
  labyrinth();
  return 0;
  */
  //cog_run(&musicplay,50);
  //cog_run(&musicplay3,50);
  int count = 0;
  wifi_start(7, 8, 115200, WX_ALL_COM);
  
  
  getFromPageId1 = wifi_listen(HTTP, "/ping");
  getFromPageId2 = wifi_listen(HTTP, "/pingdata");
  getFromPageId3 = wifi_listen(HTTP, "/status"); 
  postFromPageId = wifi_listen(HTTP, "/post");
  print("%d %d %d %d\n",getFromPageId1,getFromPageId2,getFromPageId3,postFromPageId);

  while(1)
  {    
    wifi_poll(&event, &id, &handle);       
      if(event == 'G')
      {
        //print("id: %d\n", id);
        if(id == getFromPageId1)
        {
          wifi_print(GET, handle, "ok");
          ping_around(); 
          count = 0;
          
        }
        if(id == getFromPageId2){
            //print("%d", count);                      
            if(count == 0){     
               wifi_print(GET, handle, "%s\n", stringvorne);
              //print("count0\n"); 
              count = 1;                       
            }else if(count == 1){
              //print("count1\n");
              wifi_print(GET, handle, "%s\n", stringmittevorne); 
              //print(stringmittevorne);  
              count = 2;        
            }else if(count == 2){
              //print("count2\n");
              wifi_print(GET, handle, "%s\n", stringmittehinten);
              //print(stringmittehinten);  
              count = 3;         
            }else if(count == 3){
              //print("count3\n");
              wifi_print(GET, handle, "%s\n", stringhinten);          
              count = -2;
            }            
             
        }
        if(id == getFromPageId3){
          if(!run){
            wifi_print(GET, handle, "%s\n", "ok");
          }else{
            wifi_print(GET, handle, "%s\n", "laby");
          }                    
           
        }                                         
     }else if(event == 'P'){       
        if(id == postFromPageId)
        {
          //printf("Incoming POST request\r");
          char s[50];
          wifi_scan(POST, handle, "cmd%s",   &s);
          //printf("test = %s\n", s);
          if(s[0] == 'X'){
            if(run == 0){
              run = 1;
              thread = cog_run(&labyrinth,150); 
            }else{                          
              run = 0;        
            }
          }else{
            int i = 0;
            while(s[i] != ','){
                i++;
               }
            s[i] = '\0';
             int drehen1 = atoi(s);
            int j = i + 1;
            while(s[j] != ',') {
                j++;
              }
             s[j] = '\0';
            int drehen2 = atoi(&s[i+1]);
            
            int z = j+1;
            while(s[z] != ',') {
              z++;
              }
            s[z] = '\0';
            int fahren = atoi (&s[j+1]);
            drive_goto(drehen1,drehen2);
           drive_goto(fahren,fahren);  
         }                                             
        }    
   }        
                                      
     pause(100);
  }  
}

/*labyrinth startet den Laby Modus, welches den Roboter automatisches durch 
ein Labyrinth fahren laesst.
Bricht entweder durch manuelle Eingabe oder durch hohe Abstandsmessungen ab.*/

void laby_timer() {
    int pause_time = 100;
    labyTerminate = 1000 * 60; // 10s
    while(run && labyTerminate > 0){
      labyTerminate -= pause_time; 
      pause(pause_time);
   }     
}  

/*labyrinth startet den Laby Modus, welches den Roboter automatisches durch 
ein Labyrinth fahren laesst.
Bricht entweder durch manuelle Eingabe oder durch hohe Abstandsmessungen ab.*/

void labyrinth() 
{
  //drive_goto(30,30);
  //servo_angle(16,0);
  int dist = 720;
  int start_dist = 1500;
  int spee = 20;
  int maxspeed = 30;
  double factor = .007;
  int rechts, vorne;
  int rspeed = 20;
  int lspeed = 20;
  
  int rerror, lerror;
  
  servo_angle(16,900);

  servo_angle(17,1800);
  pause(300);
  
  // ERSTE WAND FINDEN 
  drive_speed(lspeed*4,4*rspeed);
  //print("driving to wall\n");
  int p = ping(11);
  while(p > start_dist){
    // rechts   
    servo_angle(16,0);
    pause(400);
    p = ping(11);
    if(p < start_dist)
      break;
    
    // vorne   
    servo_angle(16,900);
    pause(400);
    p = ping(11);
    
  }
  
  drive_speed(0,0);
  
  servo_angle(16,0);
  pause(400);
  p = ping(10);
  if(p > start_dist)
    drive_goto(-5,5);
    
  //print("wall found\n");
  
  servo_angle(17,1200);


  cog_run(&laby_timer,150);
  pause(100);
  
  while(run)
  {
    servo_angle(16,0);
    pause(300);
    rechts = ping(11);
    
    // RECHTSKURVE
    rerror = dist - rechts;
    rspeed = spee + factor * rerror;
    lspeed = spee - factor * rerror;
    
    servo_angle(16,800);
    pause(300);
    vorne = ping(11);
    
	//print("v:%d r:%d\n",vorne,rechts);
    // ABBRUCHBEDINGUNG
    if(labyTerminate == 0 && (vorne > 4500 || rechts > 5000)){
      ////print("abbruch\n");
      run = 0;
      drive_speed(0,0);
      break;
    }     
    // KOPF AN DER WAND
    if(vorne <  dist * 1.3/* && rechts < dist * 2*/){
      if(vorne > dist * .7)
        lspeed = 1;
      else
        lspeed = -8;
      ////print("links\n");
      rspeed = spee * .75;
      /*
       if(rechts < dist * 1.2) {// links
        if(vorne > dist * .7)
          lspeed = 1;
        else
          lspeed = -8;
        ////print("links\n");
        rspeed = spee * .75;
       } else {                 // rechts
         if(vorne > dist * .7)
          rspeed = 1;
         else
          rspeed = -8;
         ////print("rechts\n");
         lspeed = spee*.75;
       }                */
    } else {
      ////print("rechts / geradeaus\n");
    }      
    /*
    if(vorne < 70 && rechts < 70){
      rspeed = -7;
      lspeed = -7;
    }     */               
    if(rspeed > maxspeed) rspeed = maxspeed;
    if(rspeed < 0) rspeed = 0;
    if(lspeed > maxspeed)lspeed = maxspeed;
    if(lspeed < -7) lspeed = -7;    
    if(abs(lspeed-rspeed) > 1.5*spee){
      lspeed *= .5;
      rspeed *= .5;
    }
    
    /*if(vorne < 950){
      if(rechts < 1500){
        lspeed = -7;
        rspeed = spee/2;
      }else{
        lspeed = spee/4;
        rspeed = -2;
      }                    
    }   */      
    //drive_rampStep(lspeed,rspeed);  
    drive_speed(lspeed,rspeed);
    ////print("v%d,r%d\n",vorne,rechts);  
  }  
  drive_speed(0,0);
  
  drive_goto(30,30);
  if(rechts > 5000)
    drive_goto(23,-24);
  servo_angle(16, 0);
  servo_angle(17, 0);
  pause(300);
  ////print("terminating\n");
  cog_end(thread);
}

void musicplaygot(){
  int port2 = 2;
  int pauset = 40;
  int c0 = 130;
  int d0 = 146;
  int e0 = 164;
  int f0 = 174;
  int g0 = 195;
  int a0 = 220;
  int h0 = 246;
  int c = 261;
  int d = 293;
  int e = 329;
  int f = 349;
  int g = 391;
  int a = 440;
  int h = 493;
  int c2 = 523;
  int cisdes = 554;
  int d2 = 587;
  int e2 = 659;
  int f2 = 698;
  int g2 = 783;
  int a2 = 880;
  int h2 = 987;
  int c3 = 1046;
  int d3 = 1174;
  int eis = 311;
  int voll = 1000;
  int ganz = 2000;
  int halbe = 500;
  int viertel = 250;
  int i = 1;
  int noten[] = {g,c,e,f,g,c,e,f,g,c,e,f,g,c,eis,f,g,c,e,f,g,c,e,f,g,c,e,f};
  int lange[] = {halbe,halbe,viertel,viertel,halbe,halbe,viertel,viertel,halbe,halbe,viertel,viertel,
  halbe,halbe,viertel,viertel,halbe,halbe,viertel,viertel,halbe,halbe,viertel,viertel,
  halbe,halbe,viertel,viertel,halbe,halbe,viertel,viertel};
  while(i > 0){ 
      for(int u = 0; u < 31; u++){
        if(noten[u] != 0){
          freqout(port2, lange[u], noten[u]); 
        }else{
          pause(lange[u]);
        }                    
      }        
  }
}
void musicplay(){
  int port2 = 2;
  int pauset = 40;
  int c0 = 130;
  int d0 = 146;
  int e0 = 164;
  int f0 = 174;
  int g0 = 195;
  int a0 = 220;
  int h0 = 246;
  int c = 261;
  int d = 293;
  int e = 329;
  int f = 349;
  int g = 391;
  int a = 440;
  int h = 493;
  int c2 = 523;
  int cisdes = 554;
  int d2 = 587;
  int e2 = 659;
  int f2 = 698;
  int g2 = 783;
  int a2 = 880;
  int h2 = 987;
  int c3 = 1046;
  int d3 = 1174;
  int i = 1;
  
  while(i > 0){  
  freqout(port2, 200, f); 
  freqout(port2, 200, g); 
  
  freqout(port2, 1000, a);
  freqout(port2, 1000, c2);
  freqout(port2, 1000, a);
  freqout(port2, 1000, g);
  
  freqout(port2, 2000, f);
  pause(1000);
  freqout(port2, 500, a);
  freqout(port2, 500, c2);
  
  freqout(port2, 1000, d2);
  freqout(port2, 1000, f2);
  freqout(port2, 1000, e2);
  freqout(port2, 1000, c2);
  
  freqout(port2, 2000, a);
  freqout(port2, 1000, g);
  freqout(port2, 500, f);
  freqout(port2, 500, g);
  
  freqout(port2, 1000, a);
  freqout(port2, 1000, c2);
  freqout(port2, 1000, a);
  freqout(port2, 1000, g);
  
  freqout(port2, 2000, f);
  pause(1000);
  freqout(port2, 500, a);
  freqout(port2, 500, c2);
  
  freqout(port2, 2000, d2);
  pause(pauset);
  freqout(port2, 500, d2);
  pause(pauset);
  freqout(port2, 500, d2); 
  freqout(port2, 500, c2);
  freqout(port2, 500, a);
  
  freqout(port2, 3000, g);
  pause(1000);
  
  freqout(port2, 500, f);
  freqout(port2, 500, g);
  freqout(port2, 3000, a);
  
  pause(3000);
  freqout(port2, 250, a);
  freqout(port2, 500, d2);
  freqout(port2, 500, e2);
  
  freqout(port2, 1500, f2);
  freqout(port2, 250, g2);
  freqout(port2, 250, f2);
  freqout(port2, 500, e2);
  freqout(port2, 500, c2);
  
  freqout(port2, 2000, a);
  freqout(port2, 1000, g);
  freqout(port2, 500, f);
  freqout(port2, 500, g);
  
  freqout(port2, 4000, a);
  
  pause(3000);
  freqout(port2,250, a);
  freqout(port2, 500, d2);
  freqout(port2, 500, e2);
  
  freqout(port2, 2000, f);
  freqout(port2, 1500, g);
  freqout(port2, 250, f);
  freqout(port2, 250, g);
  
  freqout(port2, 2000, a2);
  pause(pauset);
  freqout(port2, 1000, a2);
  freqout(port2, 500, f2);
  freqout(port2, 500, d2);
  freqout(port2, 500, f2);
  
  pause(pauset);
  freqout(port2, 1000, f2);
  freqout(port2, 3000, c2);
  //neue Seite
  pause(pauset);
  freqout(port2, 1000, c2);
  pause(3000);
  freqout(port2, 250, h);
  freqout(port2, 250, c2);
  
  freqout(port2, 1500, 554);//622;
  freqout(port2, 250, c2);
  freqout(port2, 250, h);
  freqout(port2, 1500, 466);//415
  freqout(port2, 250, h);
  freqout(port2, 250, c2);
  
  freqout(port2, 2000, h);
  freqout(port2, 1000, 466);//415
  freqout(port2, 1000, g);
  
  freqout(port2, 2000, f);
  freqout(port2, 1500, 311);//eis
  pause(40);
  freqout(port2, 250, e);
  pause(pauset);
  freqout(port2, 250, e);
  
  freqout(port2, 3000, f);
  pause(500);
  freqout(port2, 250, h);
  freqout(port2, 250, c);
  
  freqout(port2, 1500, 554);//622
  freqout(port2, 250, c2);
  freqout(port2, 250, d2);
  freqout(port2, 1000, 622);//
  freqout(port2, 500, g);
  freqout(port2, 500, a);
  int x = 1;
  while(x > 0){
  freqout(port2, 1000, h);
  freqout(port2, 1000, d2);
  freqout(port2, 1000, h);
  freqout(port2, 1000, a);
  // zeile zwei takt drei anfang
  
  freqout(port2, 2000, g);
  pause(1000);
  freqout(port2, 500, h);
  freqout(port2, 500, d2);
  
  freqout(port2, 2000, e2);
  pause(pauset);
  freqout(port2, 500, e2);
  freqout(port2, 500, g2);
  freqout(port2, 500, f2);
  freqout(port2, 500, d2);
  
  freqout(port2, 2000, h);
  freqout(port2, 1000, a);
  freqout(port2, 500, g);
  freqout(port2, 500, a);
  
  freqout(port2, 500, h);
  freqout(port2, 500, d2);
  freqout(port2, 500, h);
  freqout(port2, 500, a);
  
  freqout(port2, 2000, g);
  pause(500);
  freqout(port2, 500, g);
  freqout(port2, 500, h);
  freqout(port2, 500, d2);
  
  freqout(port2, 2000, e2);
  pause(pauset);
  freqout(port2, 500, e2);
  pause(pauset);
  freqout(port2, 500, e2);
  freqout(port2, 500, d2);
  freqout(port2, 500, h);
 
  freqout(port2, 2000, a);
  pause(pauset);
  freqout(port2, 500, a);
  pause(pauset);
  freqout(port2, 500, a);
  freqout(port2, 500, g);
  freqout(port2, 500, f);
  
  freqout(port2, 4000, g);
  
  x-- ;
  }  
  freqout(port2, 500, 5000);
  
  //i--;
  }  
  }
void musicplay3(){
  int port2 = 3;
  int pauset = 40;
  int c0 = 130;
  int d0 = 146;
  int e0 = 164;
  int f0 = 174;
  int g0 = 195;
  int a0 = 220;
  int h0 = 246;
  int c = 261;
  int d = 293;
  int e = 329;
  int f = 349;
  int g = 391;
  int a = 440;
  int h = 493;
  int c2 = 523;
  int cisdes = 554;
  int d2 = 587;
  int e2 = 659;
  int f2 = 698;
  int g2 = 783;
  int a2 = 880;
  int h2 = 987;
  int c3 = 1046;
  int d3 = 1174;
  int i = 1;
  
  while(i > 0){  
  freqout(port2, 200, a); 
  freqout(port2, 200, g); 
  
  freqout(port2, 1000, c2);
  freqout(port2, 1000, e2);
  freqout(port2, 1000, c2);
  freqout(port2, 1000, h);
  
  freqout(port2, 2000, a);
  pause(1000);
  freqout(port2, 500, c2);
  freqout(port2, 500, e2);
  
  freqout(port2, 1000, f2);
  freqout(port2, 1000, a2);
  freqout(port2, 1000, g2);
  freqout(port2, 1000, e2);
  
  freqout(port2, 2000, c2);
  freqout(port2, 1000, h);
  freqout(port2, 500, a);
  freqout(port2, 500, h);
  
  freqout(port2, 1000, c2);
  freqout(port2, 1000, e2);
  freqout(port2, 1000, c2);
  freqout(port2, 1000, h);
  
  freqout(port2, 2000, a);
  pause(1000);
  freqout(port2, 500, c2);
  freqout(port2, 500, e2);
  
  freqout(port2, 2000, f2);
  pause(pauset);
  freqout(port2, 500, f2);
  pause(pauset);
  freqout(port2, 500, f2); 
  freqout(port2, 500, e2);
  freqout(port2, 500, c2);
  
  freqout(port2, 3000, h);
  pause(1000);
  
  freqout(port2, 500, a);
  freqout(port2, 500, h);
  freqout(port2, 3000, c2);
  
  pause(3000);
  freqout(port2, 250, c2);
  freqout(port2, 500, f2);
  freqout(port2, 500, g2);
  
  freqout(port2, 1500, a2);
  freqout(port2, 250, h2);
  freqout(port2, 250, a2);
  freqout(port2, 500, g2);
  freqout(port2, 500, e2);
  
  freqout(port2, 2000, c2);
  freqout(port2, 1000, h);
  freqout(port2, 500, a);
  freqout(port2, 500, h);
  
  freqout(port2, 4000, c2);
  
  pause(3000);
  freqout(port2,250, c2);
  freqout(port2, 500, f2);
  freqout(port2, 500, g2);
  
  freqout(port2, 2000, a);
  freqout(port2, 1500, h);
  //hier ich bin
  freqout(port2, 250, f);
  freqout(port2, 250, g);
  
  freqout(port2, 2000, a2);
  pause(pauset);
  freqout(port2, 1000, a2);
  freqout(port2, 500, f2);
  freqout(port2, 500, d2);
  freqout(port2, 500, f2);
  
  pause(pauset);
  freqout(port2, 1000, f2);
  freqout(port2, 3000, c2);
  //neue Seite
  pause(pauset);
  freqout(port2, 1000, c2);
  pause(3000);
  freqout(port2, 250, h);
  freqout(port2, 250, c2);
  
  freqout(port2, 1500, 554);//622;
  freqout(port2, 250, c2);
  freqout(port2, 250, h);
  freqout(port2, 1500, 466);//415
  freqout(port2, 250, h);
  freqout(port2, 250, c2);
  
  freqout(port2, 2000, h);
  freqout(port2, 1000, 466);//415
  freqout(port2, 1000, g);
  
  freqout(port2, 2000, f);
  freqout(port2, 1500, 311);//eis
  pause(40);
  freqout(port2, 250, e);
  pause(pauset);
  freqout(port2, 250, e);
  
  freqout(port2, 3000, f);
  pause(500);
  freqout(port2, 250, h);
  freqout(port2, 250, c);
  
  freqout(port2, 1500, 554);//622
  freqout(port2, 250, c2);
  freqout(port2, 250, d2);
  freqout(port2, 1000, 622);//
  freqout(port2, 500, g);
  freqout(port2, 500, a);
  int x = 1;
  while(x > 0){
  freqout(port2, 1000, h);
  freqout(port2, 1000, d2);
  freqout(port2, 1000, h);
  freqout(port2, 1000, a);
  // zeile zwei takt drei anfang
  
  freqout(port2, 2000, g);
  pause(1000);
  freqout(port2, 500, h);
  freqout(port2, 500, d2);
  
  freqout(port2, 2000, e2);
  pause(pauset);
  freqout(port2, 500, e2);
  freqout(port2, 500, g2);
  freqout(port2, 500, f2);
  freqout(port2, 500, d2);
  
  freqout(port2, 2000, h);
  freqout(port2, 1000, a);
  freqout(port2, 500, g);
  freqout(port2, 500, a);
  
  freqout(port2, 500, h);
  freqout(port2, 500, d2);
  freqout(port2, 500, h);
  freqout(port2, 500, a);
  
  freqout(port2, 2000, g);
  pause(500);
  freqout(port2, 500, g);
  freqout(port2, 500, h);
  freqout(port2, 500, d2);
  
  freqout(port2, 2000, e2);
  pause(pauset);
  freqout(port2, 500, e2);
  pause(pauset);
  freqout(port2, 500, e2);
  freqout(port2, 500, d2);
  freqout(port2, 500, h);
 
  freqout(port2, 2000, a);
  pause(pauset);
  freqout(port2, 500, a);
  pause(pauset);
  freqout(port2, 500, a);
  freqout(port2, 500, g);
  freqout(port2, 500, f);
  
  freqout(port2, 4000, g);
  
  x-- ;
  }  
  freqout(port2, 500, 5000);
  
  //i--;
  }  
}

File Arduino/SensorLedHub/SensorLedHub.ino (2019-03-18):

#include <Wire.h>
#include <VL53L0X.h>
#include <FastLED.h>
#include <SoftwareSerial.h>
#include <Chronos.h>

FASTLED_USING_NAMESPACE

#define DATA_PIN    9
#define CLK_PIN   10
#define LED_TYPE    APA102
#define COLOR_ORDER BGR
#define NUM_LEDS    189
CRGB leds[NUM_LEDS];

#define BRIGHTNESS          96
#define FRAMES_PER_SECOND  120

const unsigned int SensorCount = 4;
const unsigned int firstPin = 3;
const uint8_t firstAddress = 0x2A;
const unsigned int maxMeasurement = 300; //Maximal valid measurement in mm
const unsigned int measurementTolerance = 10; //Allowed Sensor jitter before triggering
const unsigned int assignableLEDSegments = 2; //Number of LED segemnts assinged to every sensor

struct Sensor {
  VL53L0X sensor;
  unsigned int calibration; //Inactive Distance
  unsigned int LEDSegment[assignableLEDSegments]; //Start of the LED segment
  unsigned int LEDSegmentSize[assignableLEDSegments]; //Length of the LED segment
  CRGB color = CRGB::HotPink;
};

Sensor assembly[SensorCount];
bool initSensors();
void flashLeds(int selection);


void setup()
{
  pinMode(11, OUTPUT);
  pinMode(12, OUTPUT);
  
  assembly[0].LEDSegment[0] = 59;
  assembly[0].LEDSegment[1] = 179;
  assembly[0].LEDSegmentSize[0] = 12;
  assembly[0].LEDSegmentSize[1] = 12;
  assembly[0].color = CRGB::Yellow;

  assembly[1].LEDSegment[0] = 74;
  assembly[1].LEDSegment[1] = 163;
  assembly[1].LEDSegmentSize[0] = 12;
  assembly[1].LEDSegmentSize[1] = 12;
  assembly[1].color = CRGB::Blue;

  assembly[2].LEDSegment[0] = 90;
  assembly[2].LEDSegment[1] = 148;
  assembly[2].LEDSegmentSize[0] = 12;
  assembly[2].LEDSegmentSize[1] = 12;
  assembly[2].color = CRGB::Green;

  assembly[3].LEDSegment[0] = 105;
  assembly[3].LEDSegment[1] = 134;
  assembly[3].LEDSegmentSize[0] = 12;
  assembly[3].LEDSegmentSize[1] = 12;
  assembly[3].color = CRGB::Red;
  Serial.begin(115200);

  if (!initSensors()) {
    Serial.println("Sensors not connected properly!");
    while (1);
  }

  for (int i = 0; i < SensorCount; i++)  {
    String s = String("Sensor Address ");
    s += (i + 1);
    s += (": ");
    s += (assembly[i].sensor.getAddress());
    unsigned int testMeasurement = assembly[i].sensor.readRangeSingleMillimeters();
    Serial.print("Sensor ");
    Serial.print(i);
    Serial.print(" : ");
    Serial.println(testMeasurement);
    if (testMeasurement == 65535)  {
      s += "\nSensor ";
      s += i;
      s += " not connected properly";
    }
    else if (testMeasurement > maxMeasurement) {
      s += "\nSensor ";
      s += i;
      s += " not aligned properly";
    }
    Serial.println(s);
  }

  //Calibrate Sensors
  for (int i = 0; i < SensorCount; i++)  {
    unsigned int calibration = 0;
    for (int j = 0; j < 10; j++) {
      calibration += assembly[i].sensor.readRangeSingleMillimeters();
      delay(100);
    }
    assembly[i].calibration = calibration / 10;
  }

  FastLED.addLeds<LED_TYPE, DATA_PIN, CLK_PIN, COLOR_ORDER>(leds, NUM_LEDS).setCorrection(TypicalLEDStrip);
  FastLED.setBrightness(BRIGHTNESS);
  Serial.println("Ready");
}

void loop() {
  //Serial.println("Awaiting Input");
  delay(100);
  if (Serial.available() > 0)  {
    //Serial.println("Processing Input");
    int selection = Serial.parseInt();
    while (Serial.available()) {
      Serial.read();
    }

    if (selection == 7)  {
      fill_rainbow(leds, NUM_LEDS, 15);
      FastLED.show();
      delay(1000);
      fill_solid(leds, NUM_LEDS, CHSV( 0, 0, 0));
      FastLED.show();
    }
    else if(selection < SensorCount)  {
      flashLeds(selection);
      assembly[selection].sensor.startContinuous();
      Chronos::DateTime timeout = Chronos::DateTime::now() + Chronos::Span::Seconds(10);
      bool success = false;
      while (Chronos::DateTime::now() < timeout && !success) {
        if (assembly[selection].sensor.readRangeContinuousMillimeters() <= assembly[selection].calibration - measurementTolerance) {
          Serial.println("s");
          digitalWrite(11, HIGH);
          delay(20);
          digitalWrite(11, LOW);
          success = true;
        }
      }
      if (!success)  {
        Serial.println("t");
        digitalWrite(12, HIGH);
        delay(20);
        digitalWrite(12, LOW);
      }
      assembly[selection].sensor.stopContinuous();
    }
  }

}

void flashLeds(int selection) {
  for (int i = 0; i < assignableLEDSegments; i++)  {
    for (int j = assembly[selection].LEDSegment[i]; j < assembly[selection].LEDSegment[i] + assembly[selection].LEDSegmentSize[i] - 1; j++) {
      leds[j] = assembly[selection].color;
    }
  }
  FastLED.show();
  delay(3000);
  for (int i = 0; i < NUM_LEDS; i++) {
    leds[i] = CRGB::Black;
  }
  FastLED.show();
}



bool initSensors()  {
  //Wake all sensors
  for (int i = 0; i < SensorCount; i++)  {
    pinMode(firstPin + i, HIGH);
  }


  //Put all sensors to sleep
  for (int i = 0; i < SensorCount; i++)  {
    digitalWrite(firstPin + i, LOW);
  }
  delay(500);

  Wire.begin();

  //Wake all sensors
  for (int i = 0; i < SensorCount; i++)  {
    digitalWrite(firstPin + i, HIGH);
  }

  for (int i = 0; i < SensorCount; i++)  {
    digitalWrite(firstPin + i, HIGH);

    for (int j = i + 1; j < SensorCount - i; j++)  {
      digitalWrite(firstPin + j, LOW);
    }

    delay(100);
    if (!assembly[i].sensor.init())  {
      return false;
    }
    assembly[i].sensor.setTimeout(100);
    assembly[i].sensor.setMeasurementTimingBudget(20000);
    assembly[i].sensor.setAddress(firstAddress + i);
  }
  return true;
}

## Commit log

2019-02-20 Add files via upload
    Mit Events '5' für Success und Event '6' für Timeout
2019-02-20 Add files via upload
    Jetzt auch mit Unterscheidung 5 und 6
2019-02-25 added Arduino code
2019-02-26 Bugs gefixed in barcode_db
    [Main.py, barcode_db.py]
2019-03-16 ECAD and power calculations added
2019-03-16 Revert "ECAD and power calculations added"
    This reverts commit 656341b1b26317328b692c9bd5c7e64f68b3a181.
2019-03-18 added Sound code
    [Präsentation.blend, TonneV2.FCstd, TonneV2.obj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]
2019-03-27 Added Power constumption Calculations
    [APA102.sch, ECAD.sch, TonneV2.FCstd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]
